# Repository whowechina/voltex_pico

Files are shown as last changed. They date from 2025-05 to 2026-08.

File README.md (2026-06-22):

# Voltex Pico - Sound Voltex Style Mini Controller
[点这里可以切换到中文版](README_CN.md)

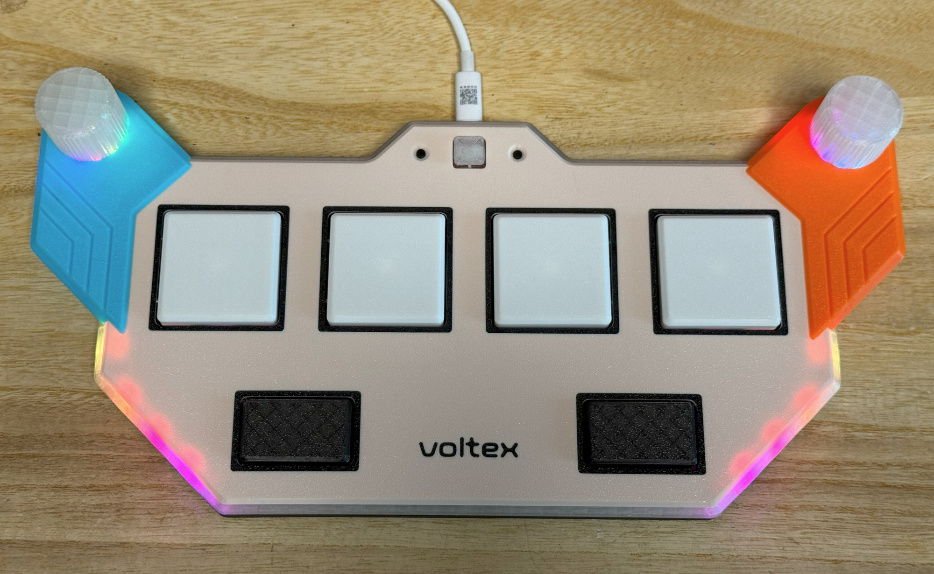
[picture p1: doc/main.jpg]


Features:
* It's ultra thin but closely replicates the feel of the arcade controller.
* Supports both Hall Effect (magnetic) switches and regular mechanical switches.
* Utilizing my new innovation: stabilizer mechanics for big and thin buttons.
* Hall Effect knobs.
* Full HID light support.
* Command line for configurations.
* All source files open.

Thanks to many respected guys/companies who made their tools or materials free or open source (KiCad, OnShape, InkScape, Raspberry things).

Special thanks to community projects and developers.
And also these projects:
* RP_Silicon_KiCad: https://github.com/HeadBoffin/RP_Silicon_KiCad
* Type-C: https://github.com/ai03-2725/Type-C.pretty
* USBemani: https://github.com/progmem/usbemani (for the Spoof mode USB descriptor)

## My Other Projects
You can check out my other cool projects.

               


* Popn Pico: https://github.com/whowechina/popn_pico
* IIDX Pico: https://github.com/whowechina/iidx_pico
* Chu Pico: https://github.com/whowechina/chu_pico
* Mai Pico: https://github.com/whowechina/mai_pico
* Diva Pico: https://github.com/whowechina/diva_pico
* AIC Pico: https://github.com/whowechina/aic_pico
* Groove Pico: https://github.com/whowechina/groove_pico
* Geki Pico: https://github.com/whowechina/geki_pico
* Musec Pico: https://github.com/whowechina/musec_pico
* Ju Pico: https://github.com/whowechina/ju_pico
* Bishi Pico: https://github.com/whowechina/bishi_pico
* Nos Pico: https://github.com/whowechina/nos_pico
* Voltex Pico: https://github.com/whowechina/voltex_pico
* Chord Pico: https://github.com/whowechina/chord_pico
* Dance Pico: https://github.com/whowechina/dance_pico
* Arcade Pico: https://github.com/whowechina/arcade_pico

## **Disclaimer** ##
I made this project in my personal time with no financial benefit or sponsorship. I will continue to improve the project. I have done my best to ensure that everything is accurate and functional, there's always a chance that mistakes may occur. I cannot be held responsible for any loss of your time or money that may result from using this open source project. Thank you for your understanding.

## About the License
It's CC-NC. So DIY for yourself and for your friend, don't make money from it. And plagiarism that doesn’t even dare to mention the original author is not acceptable. Please note that pooling orders and group buying for raw materials is acceptable. Selling off any leftover components without profit is also acceptable.

If you're interested in buying from me or some kind of commercial use, please contact me (Discord, QQ group, Wechat group or leave your contact in issue section).

## My Discord Invitation
https://discord.gg/M8f2PPQFEA

## HOW TO BUILD
### PCB and Components
* Go JLCPCB and make order with the gerber zip files (latest `Production\PCB\voltex_pico_xxx.zip`), regular FR-4 board, black or white color, **1.6mm** thickness.  
* 1x Rasberry Pico Pi Pico or pin-to-pin compatible clones (U1).  
  https://www.raspberrypi.com/products/raspberry-pi-pico
* 1x USB Type-C socket (918-418K2023S40001 or KH-TYPE-C-16P)
* 21x Reverse Mount WS2812B-3528 RGB LEDs (D1-D20).
* 18x WS2812B-4020 side emitting RGB LEDs (DL1-DL9, DR1-DR9).
* 2x TMAG-5273A1 or TMAG5273A2, in SOT23-6 (U3, U4).
* 50x 0603 0.1uF capacitors (all capacitors on the PCB, most of them are optional).
* 4x 0603 5.1kohm resistors (R1, R2, R3, R4).
* 12x U-shape 2U stabilizer steel wires, you can also harvest them from regular 2U MX stabilizers.
* 1x Kailh Choc switch for the START button (B7), and a matching blank translucent keycap.
* 2x ALPS SKHHBVA010 or compatible (6\*6\*7mm) tactile switches for the AUX buttons (B8, B9).
* 4x 1.0mm 6-pin FPC connectors, bottom contact, front flip.
* 2x 1.0mm 6-pin FPC cables, 25mm to 30mm long. Longer ones are also fine if bent properly.

* The following is for regular switch build.
  * 6x Kailh Choc low-profile switches. Choose heavy ones (70gf) for 4 BT buttons, and regular ones (50gf) for 2 FX buttons (B1-B6).

* The following is for Hall Effect switch build.
  * 1x ADG708BRUZ, 8 to 1 analog switch, in TSSOP-16 (U2).
  * 1x LM4040 Shunt Voltage Reference, get one with 2.0, 2.1, or 2.5 reference voltage, in SOT23-3 (U6).
  * 1x LP5907MFX-4.5 or TPS7A2042PDBVR LDO, in SOT23-5 (U7).
  * 6x SS49E or compatible linear Hall Effect sensors, in SOT23-3 (H1-H6).
  * 1x 10ohm resistor, 0603 (R5).
  * 1x 3.3V Zener diode, in SOD-123 or SOD-123F, such as BZT52H-C3V3 (Z1).
  * 6x low profile magnetic switches, Gateron/NuPhy Jade Mini or Jade Pro Mini, or Kailh Star Magnetic Mini. (B1-B6).
  * 4x heavy springs (60gF+) for low-profile switches, to replace the original ones in 4 BT switches. You may buy or harvest them from Kailh Choc heavy switches.

* This picture shows a soldered PCB (there might be changes in newer versions of PCB). It's a Hall Effect switch build.  
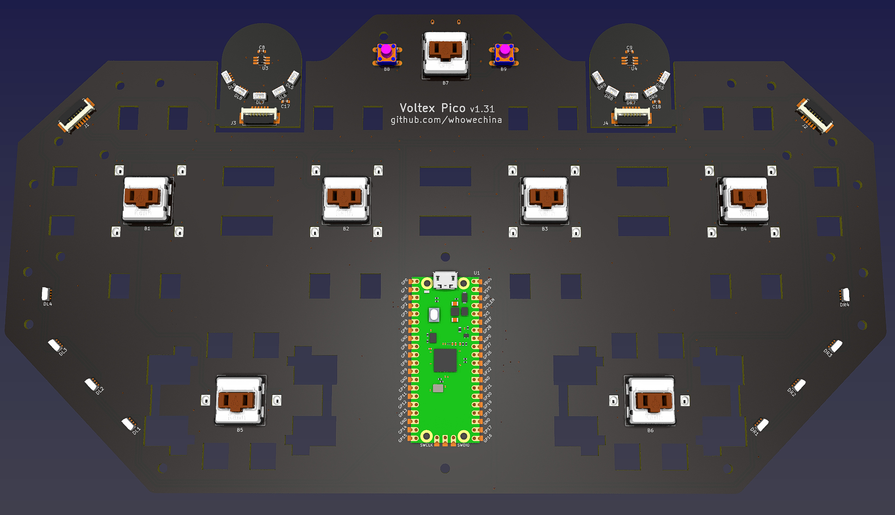
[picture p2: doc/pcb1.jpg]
    
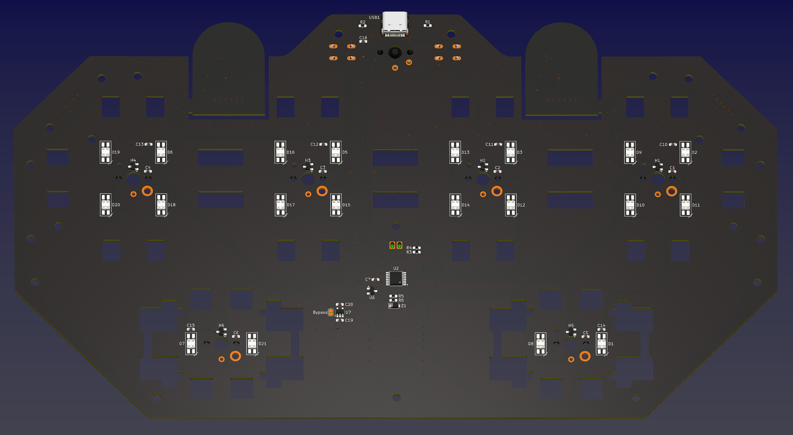
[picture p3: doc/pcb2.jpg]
  

### Important Tips for Soldering
* Be careful of 2 pin holes. It's a common oversight to either forget to solder them or to leave air bubbles during the process. To avoid this, solder slowly from one side of the hole, using minimal solder wire and a generous amount of flux.
* Reverse mount LEDs are soldered at the bottom side of the PCB.
* D4 actually requires a regular WS2812B-3528 RGB LED, not a reverse mount one. We can make one from a reverse mount one. Just bend the 4 feet to the bottom and it becomes a regular WS2812B-3528.  
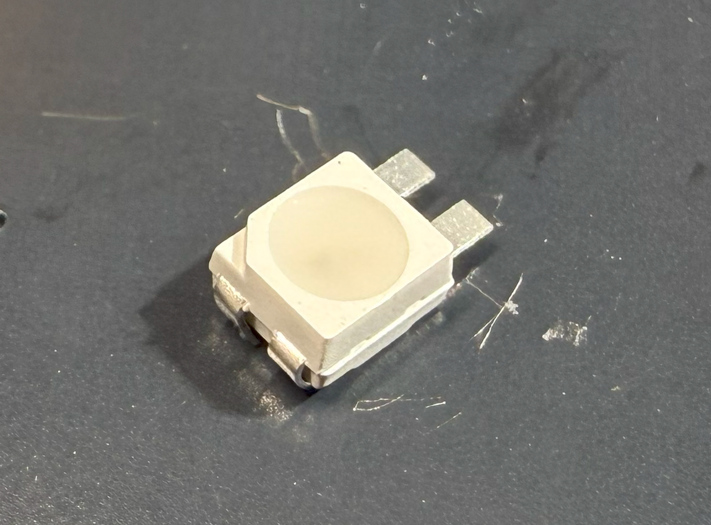
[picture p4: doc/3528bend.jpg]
  
* Be careful with WS2812B-4020 orientation. DL1 to DL4, and DR1 to DR4 are side facing, while the DL5 to DL9 and DR5 to DR9 are top facing. 
* Leave the DCDC (U5) empty and short the corresponding BYPASS jumper.
* You don't need to solder all the capacitors, it's fine to just solder the ones right beside ICs.
* Z1 is to protect the Pico from excessive voltage, don't ignore it.
* There are many LDOs and shunt voltage reference models, as long as they have the same form factor, pinout and voltage, you can use them. Best LDO voltages are 4.0 to 4.5V, they should not go higher than 4.5V, as the USB voltage under load could be lower than it. The shunt voltage reference should be 2.0 to 2.5V, roughly half of the LDO voltage.
* For regular switch build, you need to solder the switches onto the PCB. For Hall Effect switch build, you don't need to solder the switches, just make sure the magnets are aligned with the small white circles on the PCB.

### Test the PCB
* You can test the PCB now, put the firmware in.
* Side LEDs and Knob LEDs should light up in a rainbow pattern.
* Button LEDs respond to the button presses (magnetic switches need to be temporarily put on and calibrated).
* Voltex Pico should be recognized as a USB HID device, here's the test page.  
  https://whowechina.github.io/iidx_pico/Tools/gamepad_test.html
* Move a magnetic screwdriver tip close to the TMAG5273 sensor, you'll notice the corresponding axis move in the test page. Please check both sensors.

### Sensor PCB Separation and Soldering
* If everything works fine, you can cut off (or even bend and snap) 2 small sensor boards from the main board.
* Connect the sensor PCBs to the main PCB using FPC cables. Older PCB revisions do not have FPC connectors, so solder short flexible wires instead.  
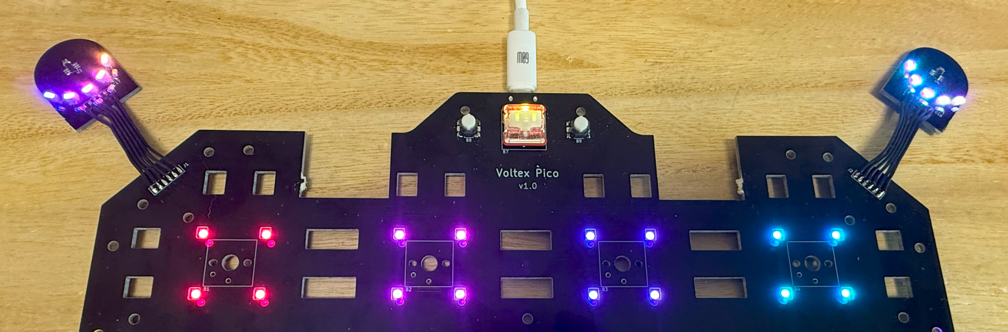
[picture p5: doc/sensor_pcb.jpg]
  

### 3D Printing
#### Printing parameters  
* PLA or PETG.
* Layer height: 0.2mm
* Support: No, unless mentioned.
* Files are always in millimeter unit, not inch.
* Files with `_Insert` in their names means it's for heatset inserts. M2 inserts are M2\*3mm\*3mm, M3 inserts are M3\*4mm\*4mm.

#### 2x Knob Parts
* Knob: `Production\3DPrint\* - Knob.stl`, clear, semi-transparent. Print it upside down. 
* Bearing Fixer: `Production\3DPrint\* - Bearing Fixer.stl`.
* Magnet Seat: `Production\3DPrint\* - Magnet Seat.stl`.

#### Button Parts
For regular switch build, choose Choc V1 or Choc v2 keycaps according to your switch type. For Hall Effect switch build, always choose Choc V2 ones.
**For all button keycaps, print them upside down.**
Note that if your switches are a little taller than usual, you need to use the `*_TallFix.stl` files for Main and FX buttons.

* Main BT: `Production\3DPrint\* - BT Choc V?.stl`, white.
* FX BT: `Production\3DPrint\* - FX-? Choc V?.stl`, smokey transparent. Support required.

#### Wing Parts
* Wing Base: `Production\3DPrint\* - * Wing Base.stl`, black.
* Wing Cover: `Production\3DPrint\* - * Wing Cover.stl`, cyan for the left, orange for the right. Print it upside down.

### Housing Parts
* Base: `Production\3DPrint\* - Base.stl`, black.
* Support: `Production\3DPrint\* - Support.stl`, clear, semi-transparent.
* Panel: `Production\3DPrint\* - Panel Combo.3mf`, white or close-to-white, with logo and patterns in black if you have multi-color system. Print it upside down.  

### Thin Stabilizing Mechanism for Big Button 
Before assembly, I'm going to introduce a new thin stabilizing mechanism for big buttons. I designed it so a slim Voltex Pico is possible.

Stabilizing a button means to make the button not wobble when pressed. A wobbling button is like a seesaw, corners for the button don't go up and down in sync, which makes the button feel bad and not reliable.

Stabilizing a big button is never a problem for arcade, simply because arcade cabs have enough vertical space. They can use so called "tube guide" stabilizing. As long as the tube is long enough (versus the gap between the tube and the shaft), buttons can only move or twist horizontally a little bit, but never wobble like a seesaw. 

Technically, for a slim controller which only has millimeters of vertical space, we can still use tube guide, but such a small tube and shaft will be very difficult to make or harvest, not to mention the sliding surface material. In short words, it's not feasible for DIYers. So we have to use a lever based stabilizing mechanism, like we do in the modern keyboards.

Long keyboard keycaps are "1-dimensional", you only need one stabilizer on their X-axis. But for big arcade buttons - big cicle or square - they need "2-dimensions" of stabilizing. So people just drop in 2 stabilizers, placed perpendicular to each other. Technically this will work. But there come new problems.
  * Vertical space for the stem and the stabilizer is not ideal for a slim controller.
  * Requires accurate keycap stem holes (connecting both the keyswitch and the stabilizer), tiny misalignment can cause stress and bring excessive friction.
  * Both FDM and SLA 3D printing have their own tolerances, which can cause misalignment easily.

So here I'm introducing my way.
First of all, I'm still using a lever-based stabilizing, just like the one in keyboards. A keyboard stabilizer has a U-shape steel lever which stays in two housing units (we call them "stabilizer base"). It rotates around its shaft side and drives two connectors (stems) to move up and down simultaneously.

My change is, remove the housing units and the stems, let the U-shape steel lever drive the keycap directly. With the stems removed, coupling of the keycap and the lever is much more lenient to misalignment; with the housing units removed, the vertical space is much smaller, which is ideal for a slim controller.

The "bearing" for the lever is printed along with the the bottom housing. The keycaps have small holes for the lever arms to go through. A FDM 3D printer can print them easily.

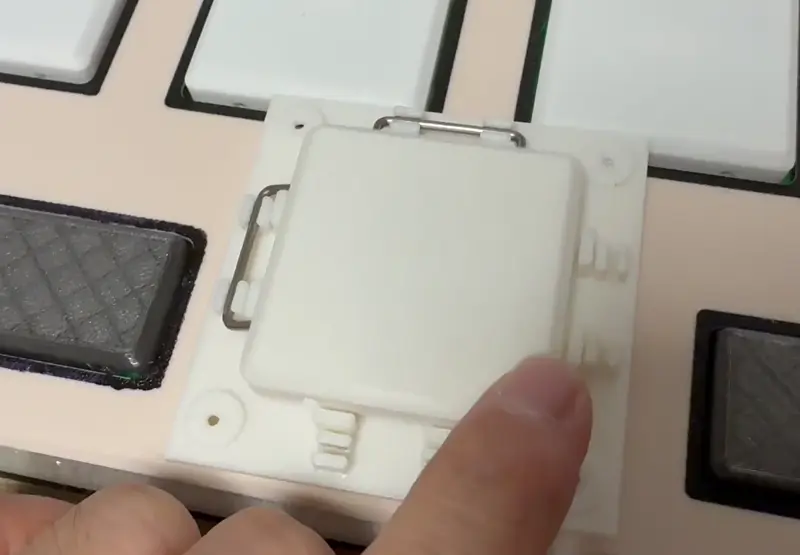
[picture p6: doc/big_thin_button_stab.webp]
  

The Voltex Pico uses this new stabilizing mechanism for the big BT buttons as well as the FX buttons.

### Assembly
#### Other components needed
* 6x **M2.5\*(14mm-16mm) screws** for fixing the magnet seat to the knob.
* 8x **M2\*6mm screws** for fixing the bearing (bearing fixer to the wing cover).
* 6x **M2\*8mm screws** for fixing wing bases to the wing cover, **M2\*6mm** if using heatset inserts.
* 12x **M3\*(4mm-5mm) screws** for fixing the PCB to the base parts.
* 10x **M3\*8mm screws** for fixing the base, wing base, support and the panel. **M3\*6mm** if using heatset inserts.
* 2x 6702zz (15x21x4mm) bearings for the knobs.
* 2x round magnets, 5mm diameter, 1.5mm or 2mm tall, MUST be radially/diametrically magnetized (N-S poles on the curved side).
* Some thin tape (such as acetate tape or high-temp teflon tape) to fix the magnets in place.
* Some 10mm diameter silicone anti-slip pads for the bottom.  
* Some 1mm thick soft felt sheet for damping the knobs.

#### Steps
1. We'll start with the bearings. They should be inserted into wing parts. Fix them using bearing fixers and M2\*6mm screws.  
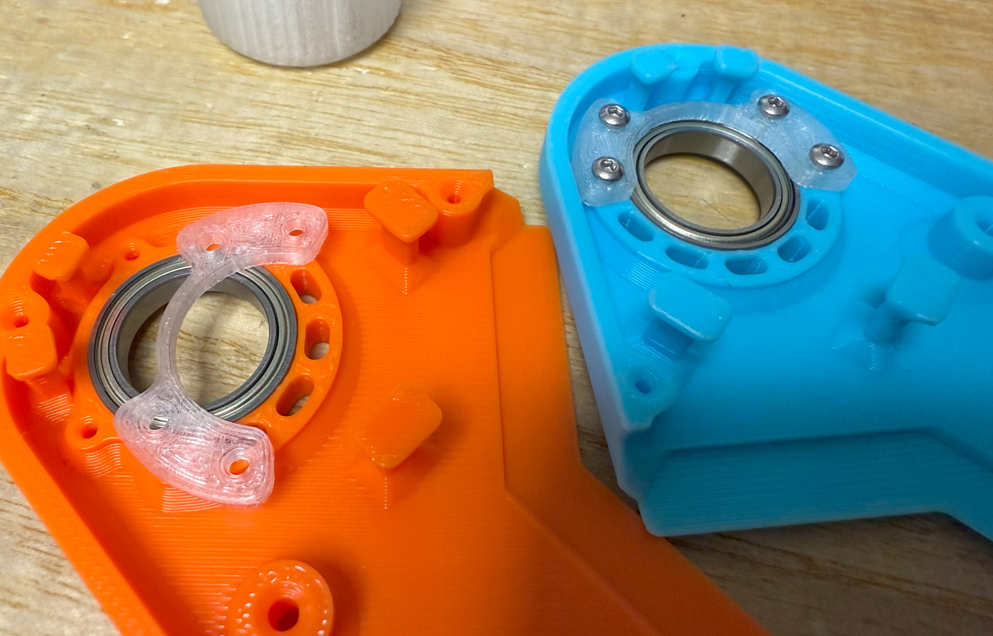
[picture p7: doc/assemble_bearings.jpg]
   

2. Cut a ring from the soft felt sheet to dampen the knob. If you feel this is too difficult, you can apply some layers of felt between the knob and the sensor PCB, it works too.   
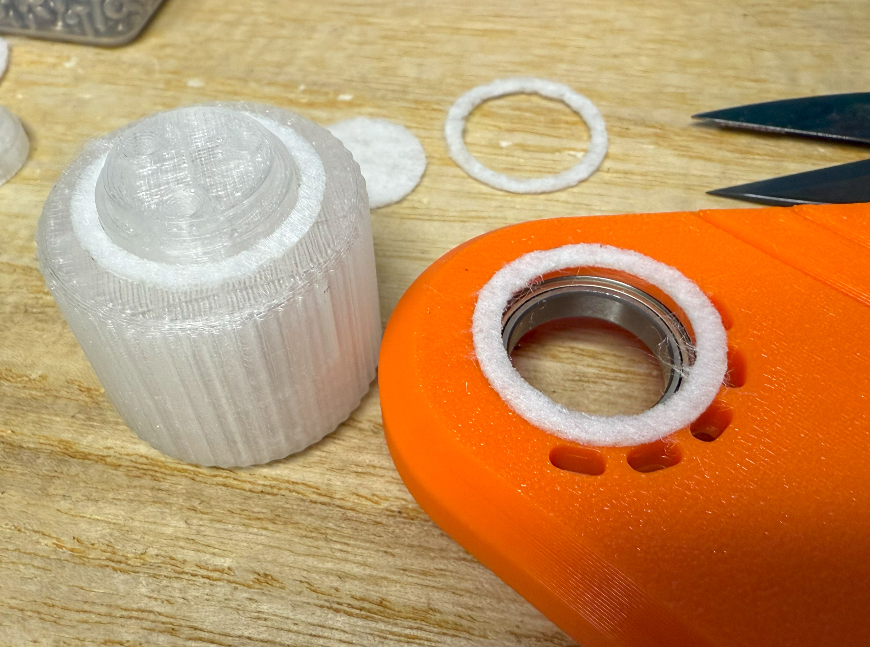
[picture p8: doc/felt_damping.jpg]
   

3. Fix the knob to the bearing with the magnet set and the M2.5 screws (long screws help reinforce the knob shaft). Then put the magnet into the center seat. If you have some thin tape, apply it as a seal so magnet won't fall out.  
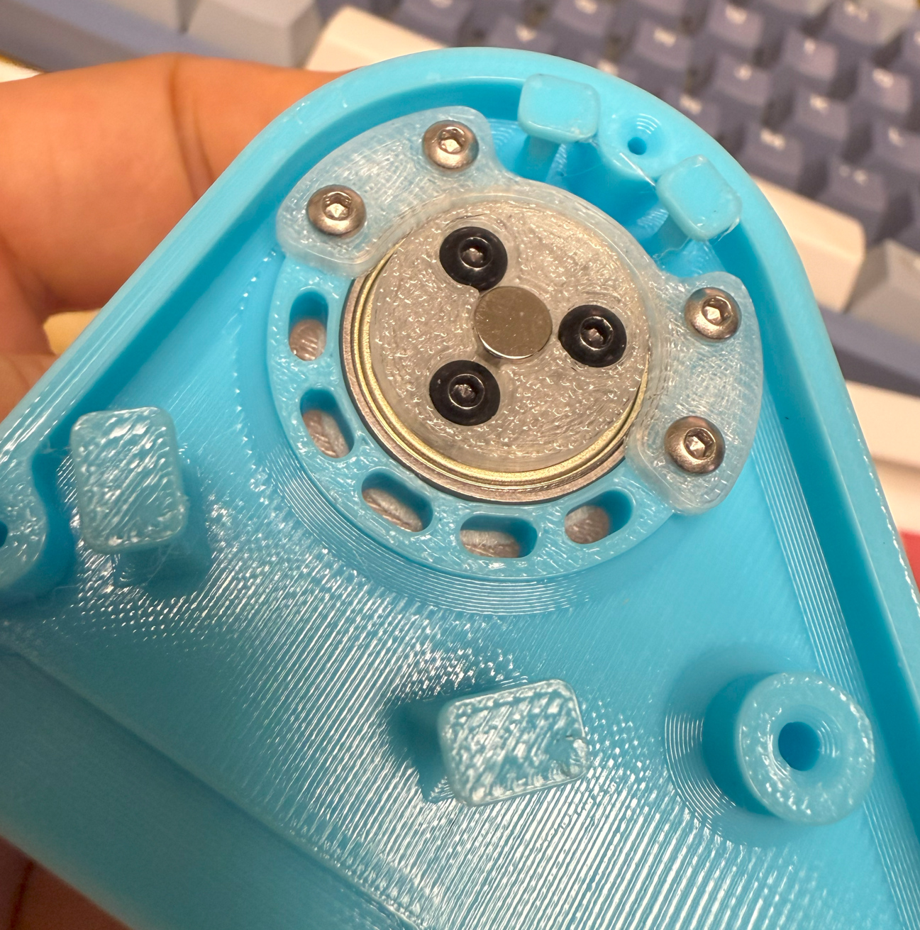
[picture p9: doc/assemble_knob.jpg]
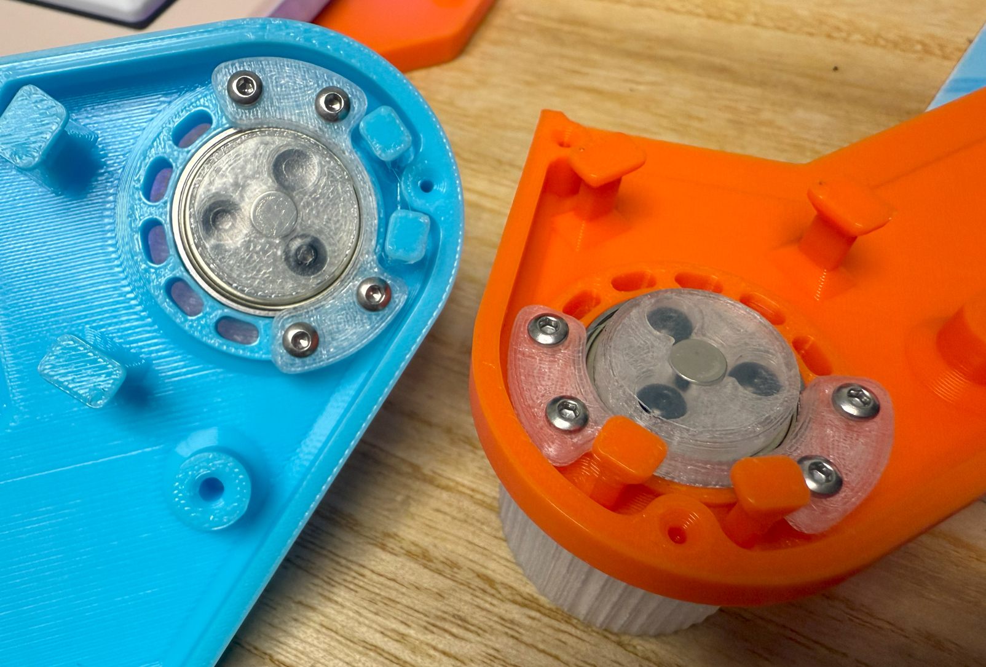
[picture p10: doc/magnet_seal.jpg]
    

4. Put the main PCB into the base part, and sensor PCBs into the wing base parts. Use M3\*(4mm-5mm) screws to fix the PCB to the base parts.  
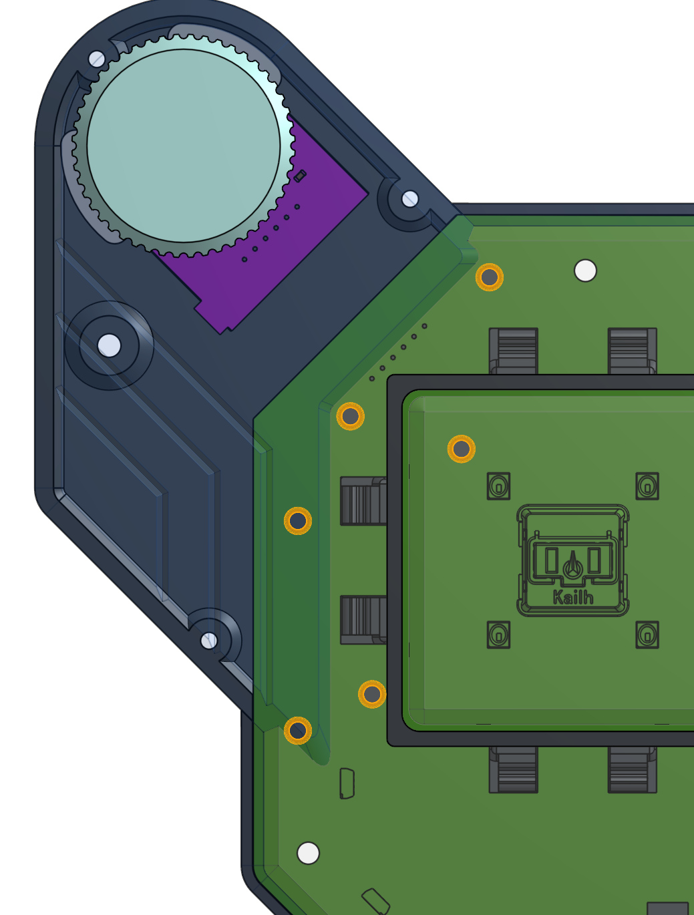
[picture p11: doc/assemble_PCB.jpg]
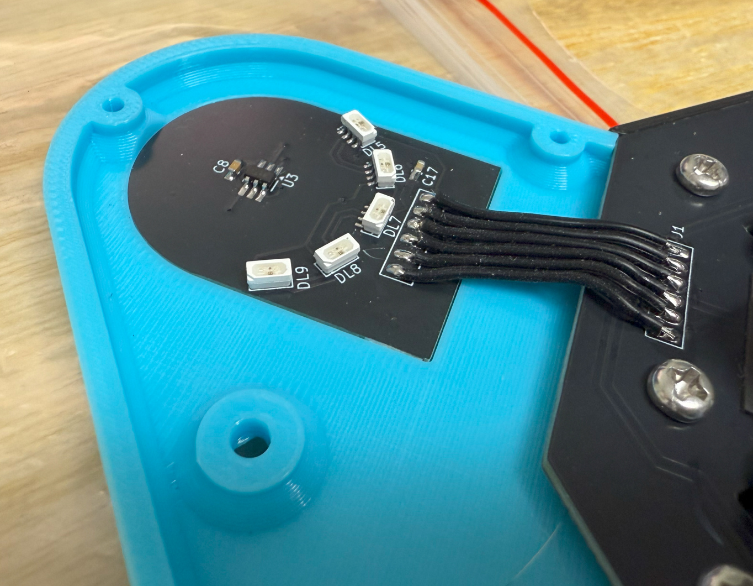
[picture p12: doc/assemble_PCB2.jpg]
    

5. Time to install keycaps to the stabilizer. It's simple, just look at the pictures. You can apply some thin poron pads to dampen the keycap noise, but it's not necessary. Some lubricant can be applied to the lever shaft, this makes the movement smoother. For Hall Effect version, you can use 704 RTV silicone to stick the switches to the PCB, or not - it's totally fine.  
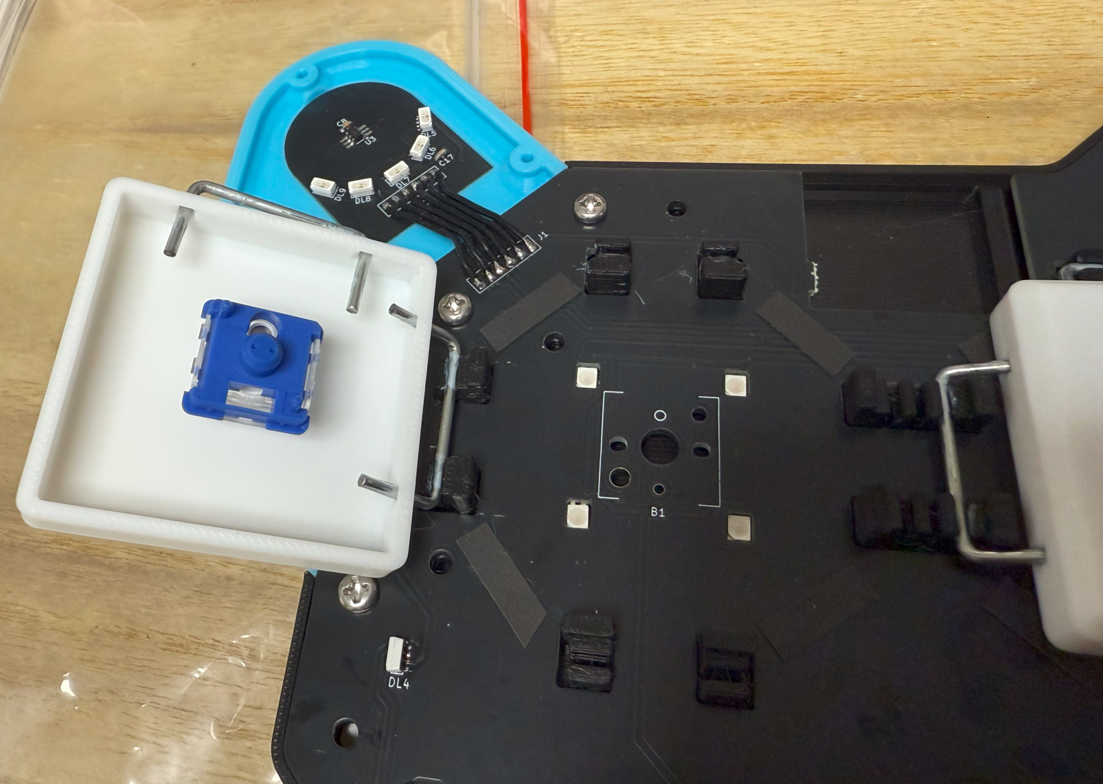
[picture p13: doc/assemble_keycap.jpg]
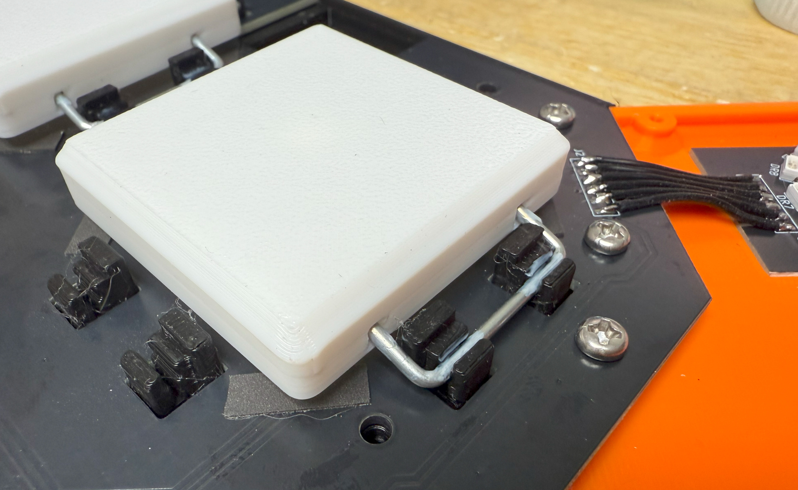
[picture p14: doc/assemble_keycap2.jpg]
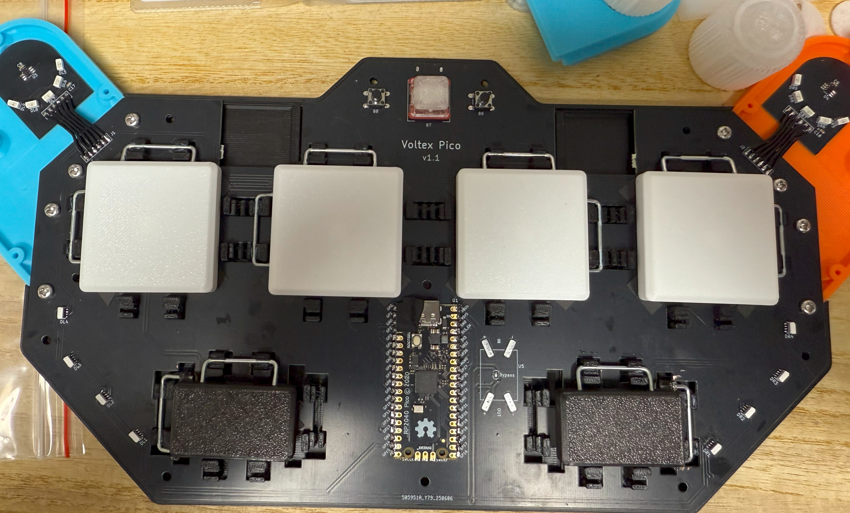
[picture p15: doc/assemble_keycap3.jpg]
     

6. Put on the support and the panel. Use M3\*(8mm-10mm) screws to fix the base. Leave the two screws on the wing base empty for now.

7. Put on the wing covers (which already have knobs on them), use M2\*(8mm-10mm) screws to fix them to the wing cover (see the picture for M2 screws). And use M3\*(8mm-10mm) screws on the remaining screw holes (one at each side). Apply silicone pads, they don't look nice but they prevent the controller from sliding on the table.   
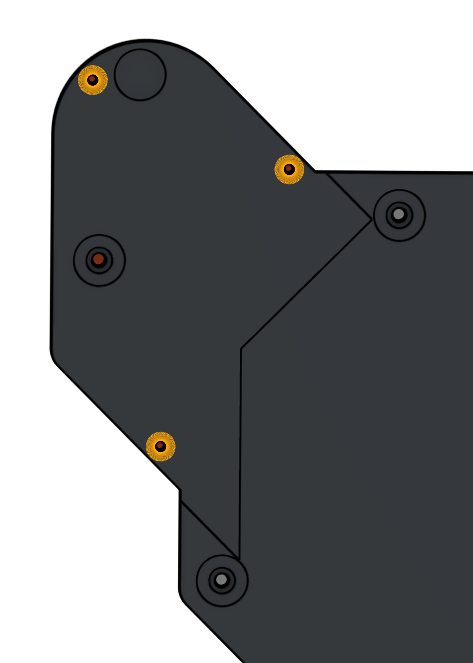
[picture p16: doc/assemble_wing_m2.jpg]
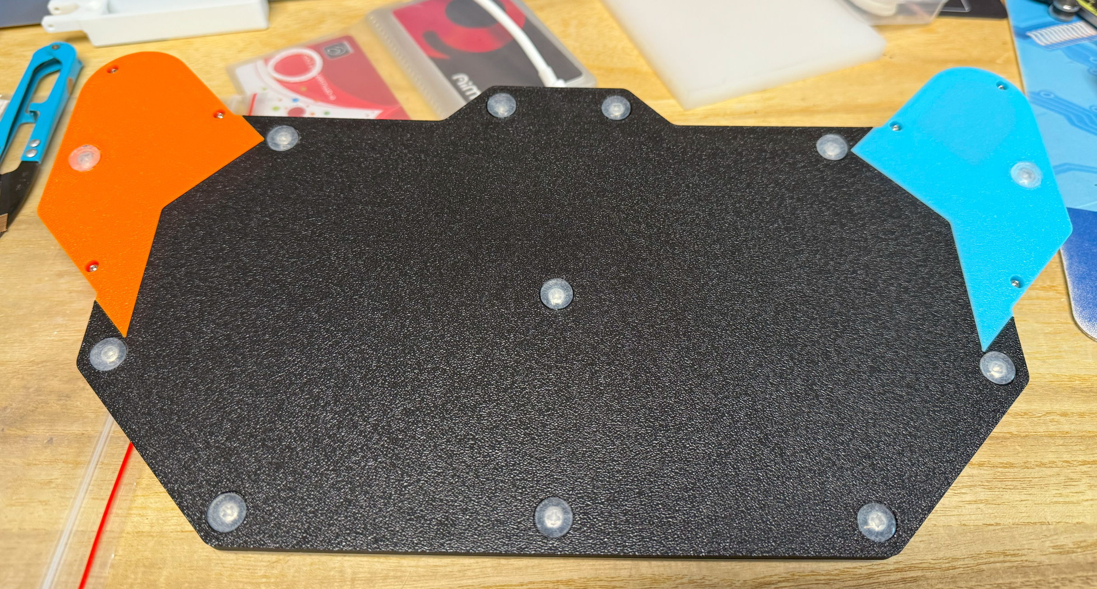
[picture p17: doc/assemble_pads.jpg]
    
   
8. Congratulations! You have finished the assembly.  
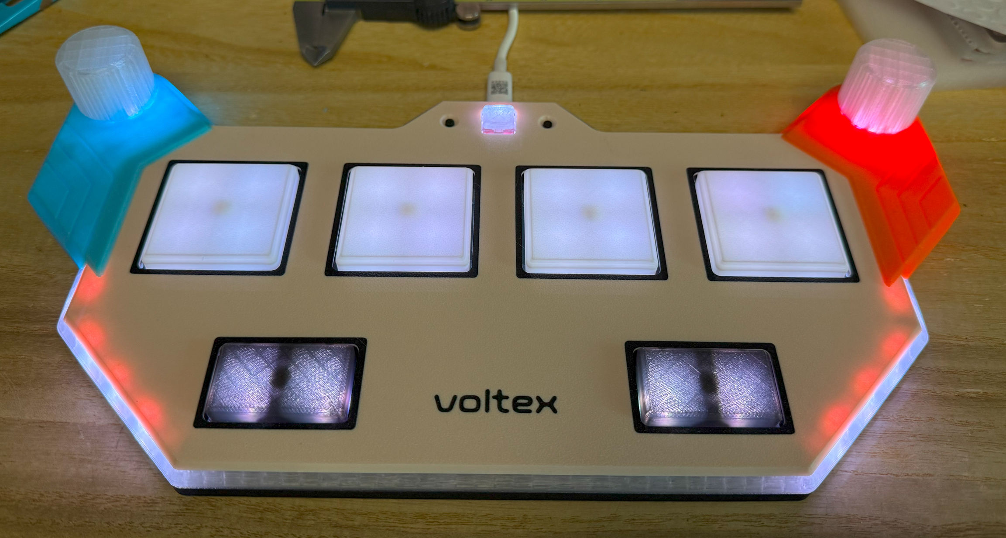
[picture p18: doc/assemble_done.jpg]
   

#### Caution
* Each 3D printer and filament has its own tolerance. If you find the holes on the keycap are too tight, use a needle or knife to enlarge them a little bit.
* Screws are easy to break the 3D printed parts. So don't screw them too tight. When you notice the resistance suddenly increases, stop screwing.

### Firmware
* UF2 file is in `Production\Firmware` folder.
* For the new build, hold the BOOTSEL button while connect the USB to a PC, there will be a disk named "RPI-RP2" show up. Drag the UF2 firmware binary file into it. That's it. There's a small hole at the bottom side, it is facing right to the BOOTSEL button.
* If it's already running Voltex Pico firmware, you can either use "update" in command line or hold down at least 4 buttons while connecting to USB to enter update mode.
* To access the command line, you can use this Web Serial Terminal to connect to the USB serial port of the controller. (Note: "?" is for help)  
  https://whowechina.github.io/iidx_pico/Tools/cli_tool.html

### Usage
* If you built a Hall Effect switch version, you need to calibrate first (`calibrate` command). You can set trigger and reset point in command line.
* Just plug it in and play.
* You can set knob resolution by `knob rate` command.
* You can set trigger and reset point by `trigger` command (only for Hall Effect switch version).
* Hold the left auxiliary button while plugging in to enter Konami spoof mode; the right for regular mode.

## CAD Source File
I'm using OnShape free subscription. It's powerful but it can't archive original designs to local, so I can only share the link here. All model files are exported from this online document.  
  https://cad.onshape.com/documents/757c9485a30088ef0335481e/w/af98e079c47cba7d81086e65/e/9703cb81cc6ed9c6ec563897

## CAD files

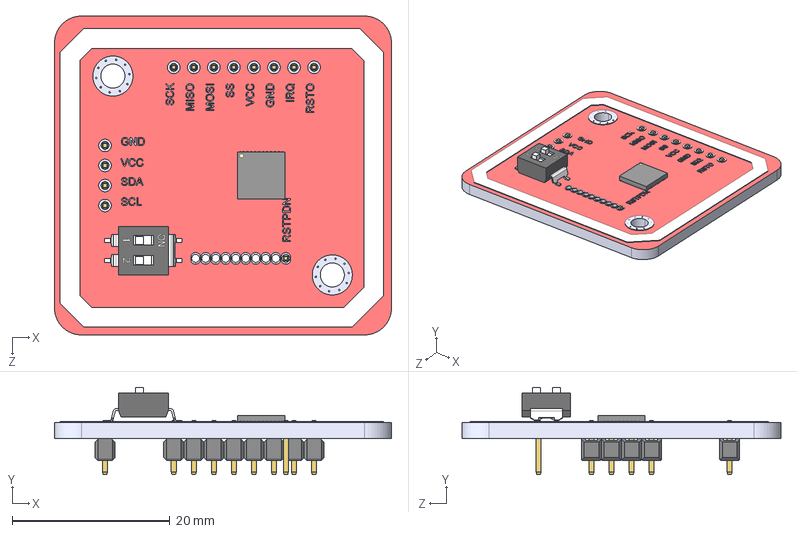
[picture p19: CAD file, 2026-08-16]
PCB/jumbo/3dmodels/PN532_NFC_Assembly.STEP
42.7 x 11.0 x 40.4 mm
NFC_MODULE_1
Pin Stand 2.54mm_1 x 12
QFN40 (6x6)_1
Switch_2_1
pin_my_1 x 13

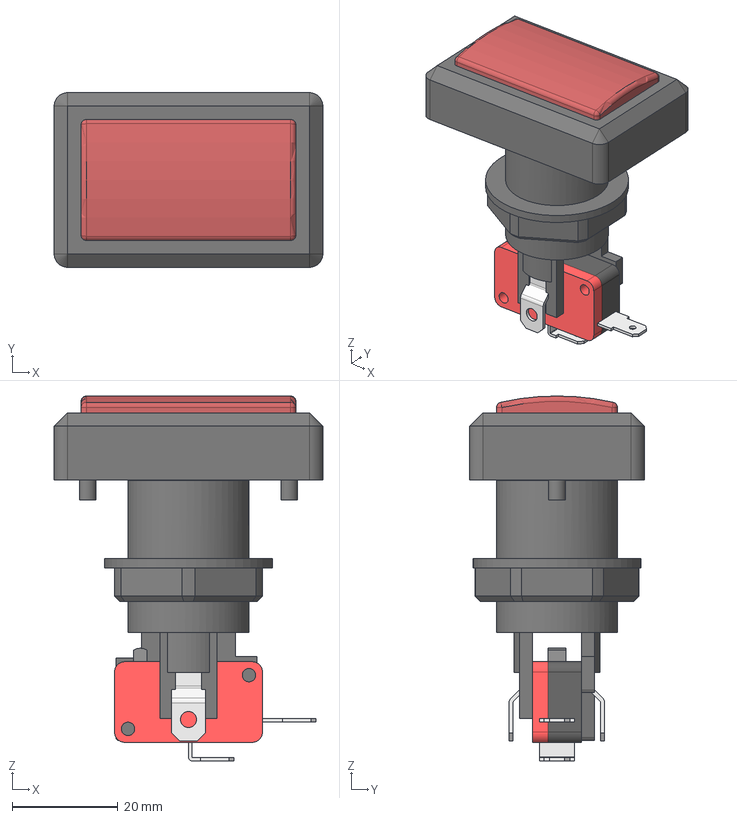
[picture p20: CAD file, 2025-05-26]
PCB/jumbo/3dmodels/Credit Button Assy (Groovy).step
50.8 x 33.0 x 69.0 mm
Button
Nut
Switch

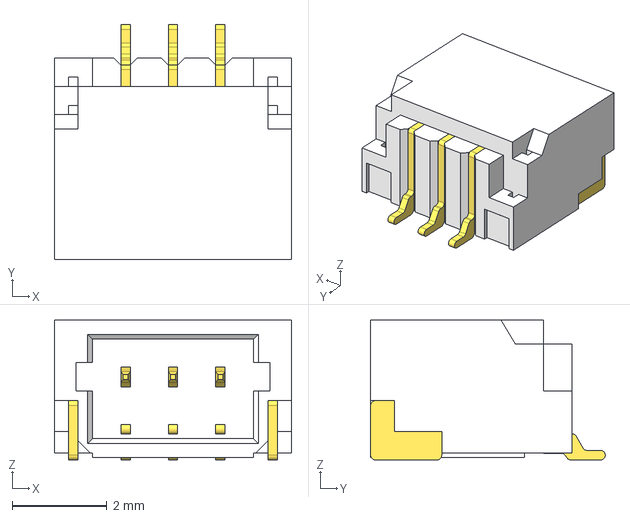
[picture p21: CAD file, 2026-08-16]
PCB/jumbo/3dmodels/SM3B-SRSS-TB.step
5.00 x 4.95 x 2.95 mm

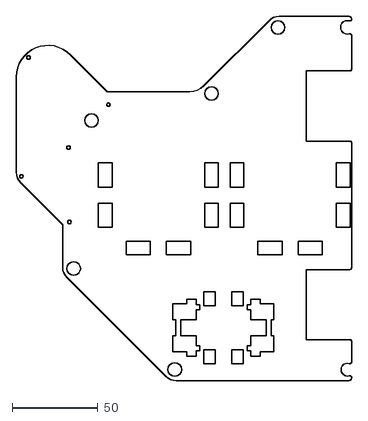
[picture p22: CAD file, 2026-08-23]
PCB/jumbo/Voltex Jumbo - PCB EdgeCut.dxf
195.9 x 212.8

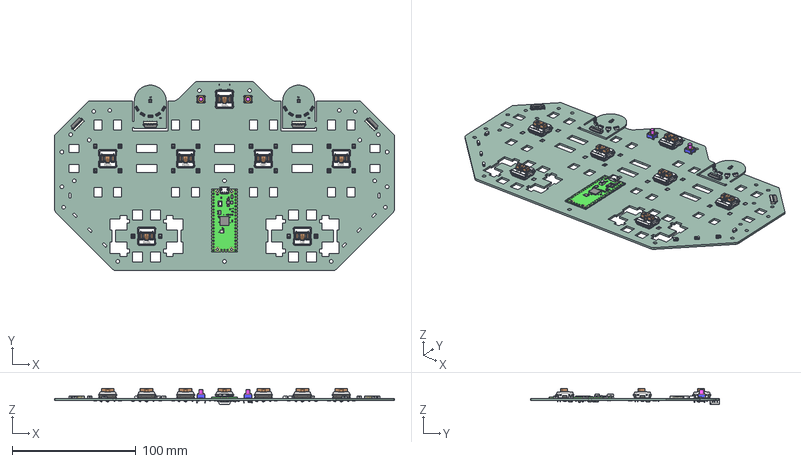
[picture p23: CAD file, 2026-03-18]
PCB/pico/voltex_pico_3d.step
275.0 x 153.0 x 13.1 mm
User Library-WS2812-4020 x 18
SMD WS2812B-3535 x 21
skhhbva010 x 2
FPC6P_1.0mm_Bottom_Contact_Flip x 4
PCB, Raspberry Pi Pico-R3
MicroUSB Port, Raspberry Pi Pico-R3
RP2040 Microcontroller, Raspberry Pi Pico-R3
SW1, Tact Switch, Raspberry Pi Pico-R3
D1, Diode, Schottky, Raspberry Pi Pico-R3
D2, QSME-C194, LED, Raspberry Pi Pico-R3
L1, Inductor, Raspberry Pi Pico-R3
U2, RT6150B-33GQW, Buck Boost Converter, Raspberry Pi Pico-R3
U3, W25Q16JVUXIQ, Serial NOR Flash 16 Mbit, Raspberry Pi Pico-R3
Q1, MOSFET, DMG1012T, Raspberry Pi Pico-R3
X1, X12M000000S096, 12 Mhz Crystal Resonator, Raspberry Pi Pico-R3
SMD Resistor, Configurable, Raspberry Pi Pico-R3_R1
SMD Resistor, Configurable, Raspberry Pi Pico-R3_R2
SMD Resistor, Configurable, Raspberry Pi Pico-R3_R3
SMD Resistor, Configurable, Raspberry Pi Pico-R3_R4
SMD Resistor, Configurable, Raspberry Pi Pico-R3_R5
SMD Resistor, Configurable, Raspberry Pi Pico-R3_R6
SMD Resistor, Configurable, Raspberry Pi Pico-R3_R7
SMD Resistor, Configurable, Raspberry Pi Pico-R3_R8
SMD Resistor, Configurable, Raspberry Pi Pico-R3_R9
SMD Resistor, Configurable, Raspberry Pi Pico-R3_R10
SMD Resistor, Configurable, Raspberry Pi Pico-R3_R11
SMD Resistor, Configurable, Raspberry Pi Pico-R3_R12
SMD Resistor, Configurable, Raspberry Pi Pico-R3_R13
SMD Resistor, Configurable, Raspberry Pi Pico-R3_R14
SMD Resistor, Configurable, Raspberry Pi Pico-R3_R15
SMD Capacitor, Configurable, Raspberry Pi Pico-R3_C1
SMD Capacitor, Configurable, Raspberry Pi Pico-R3_C2
SMD Capacitor, Configurable, Raspberry Pi Pico-R3_C3
SMD Capacitor, Configurable, Raspberry Pi Pico-R3_C4
SMD Capacitor, Configurable, Raspberry Pi Pico-R3_C5
SMD Capacitor, Configurable, Raspberry Pi Pico-R3_C6
SMD Capacitor, Configurable, Raspberry Pi Pico-R3_C7
SMD Capacitor, Configurable, Raspberry Pi Pico-R3_C8
SMD Capacitor, Configurable, Raspberry Pi Pico-R3_C9
SMD Capacitor, Configurable, Raspberry Pi Pico-R3_C10
SMD Capacitor, Configurable, Raspberry Pi Pico-R3_C11
SMD Capacitor, Configurable, Raspberry Pi Pico-R3_C12
SMD Capacitor, Configurable, Raspberry Pi Pico-R3_C13
SMD Capacitor, Configurable, Raspberry Pi Pico-R3_C14
SMD Capacitor, Configurable, Raspberry Pi Pico-R3_C15
SMD Capacitor, Configurable, Raspberry Pi Pico-R3_C16
SMD Capacitor, Configurable, Raspberry Pi Pico-R3_C17
SMD Capacitor, Configurable, Raspberry Pi Pico-R3_C18
C_0603_1608Metric x 20
SW_Kailh_Choc_V1 x 7
TSOT-23-6 x 2
D_SOD-123F
Insulator 698B116-X64-211
Contacts 698B116-X64-211
Shell 698B116-X64-211
R_0603_1608Metric x 6
SOT-23-3 x 7
TSSOP-16_4.4x5mm_P0.65mm
SOT-23-5
voltex_pico_PCB

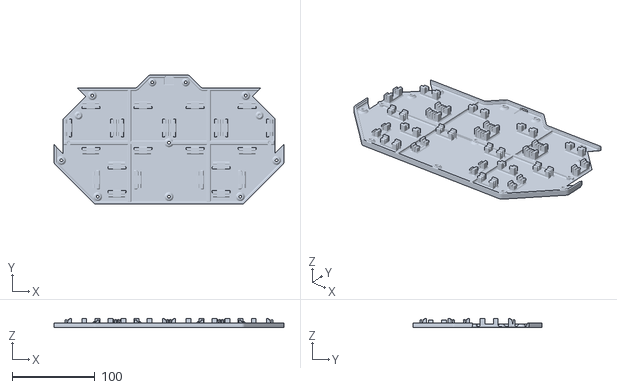
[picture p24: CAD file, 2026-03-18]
Production/3DPrint/Voltex Pico - Base.stl
278.2 x 156.2 x 11.4

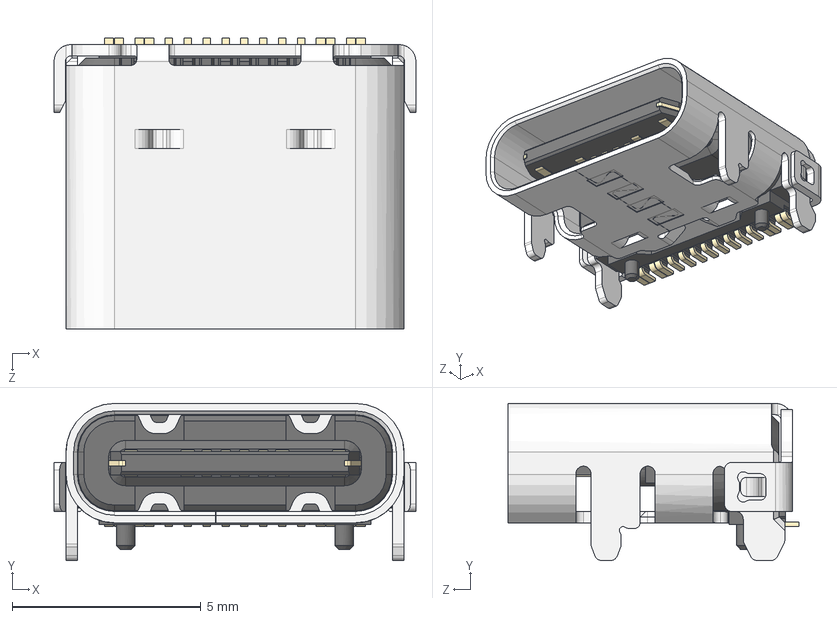
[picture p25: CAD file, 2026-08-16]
PCB/jumbo/3dmodels/698b116-264-211.STEP
9.58 x 4.16 x 7.71 mm
Insulator 698B116-X64-211
Contacts 698B116-X64-211
Shell 698B116-X64-211

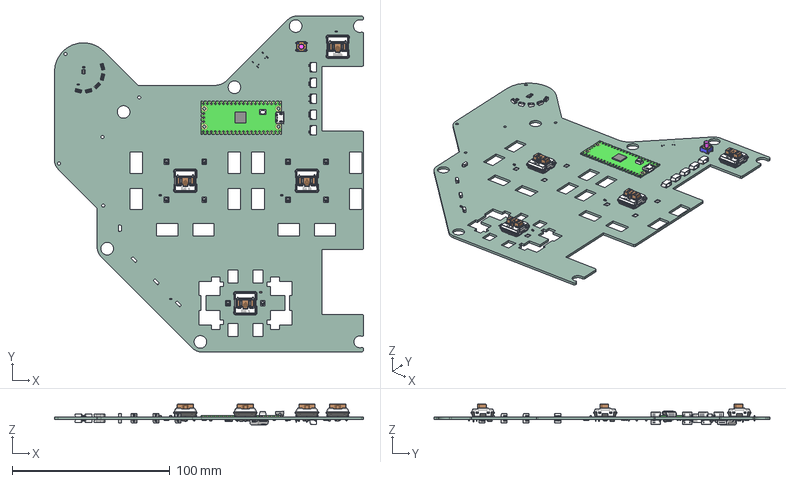
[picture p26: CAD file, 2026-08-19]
PCB/jumbo/voltex_jumbo_3d.step
195.9 x 212.8 x 13.1 mm
4778F300-7501-4A7A-8274-3BA11C4BFE81 x 18
skhhbva010
SMxB-SRSS-TB x 9
PCB, Raspberry Pi Pico-R3
MicroUSB Port, Raspberry Pi Pico-R3
MicroUSB Port, Raspberry Pi Pico-R004
RP2040 Microcontroller, Raspberry Pi Pico-R3
SW1, Tact Switch, Raspberry Pi Pico-R3
C_0603_1608Metric x 18
SOT-23-3 x 7
TSOT-23-6 x 2
SW_Kailh_Choc_V1_cp x 4
SMD WS2812B Mini v6 x 11
D_SOD_123F
Insulator 698B116-X64-211
Contacts 698B116-X64-211
Shell 698B116-X64-211
R_0603_1608Metric x 6
TSSOP-16_4.4x5mm_P0.65mm
SOT-23-5
voltex_jumbo_PCB

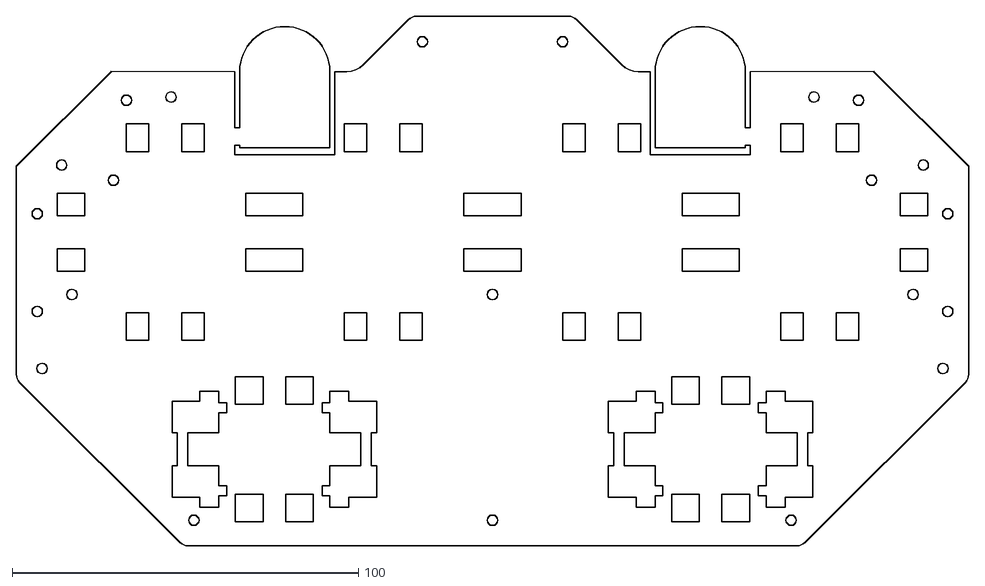
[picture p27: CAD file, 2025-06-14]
PCB/pico/Voltex Pico - PCB Profile.dxf
275.0 x 153.0

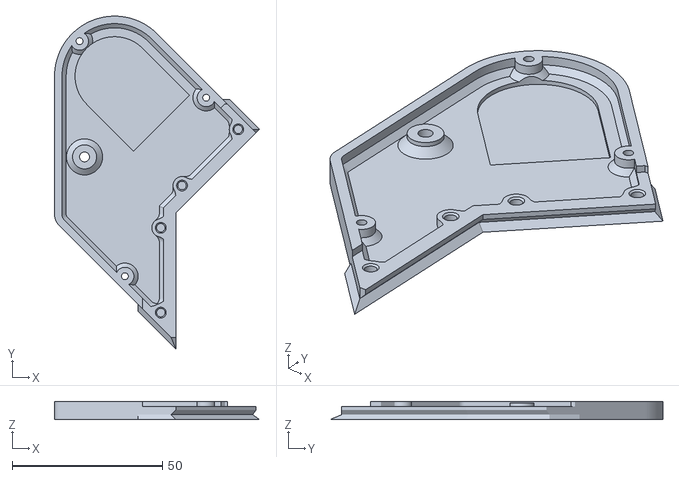
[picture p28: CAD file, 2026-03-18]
Production/3DPrint/Voltex Pico - Left Wing Base.stl
68.2 x 110.7 x 6.00

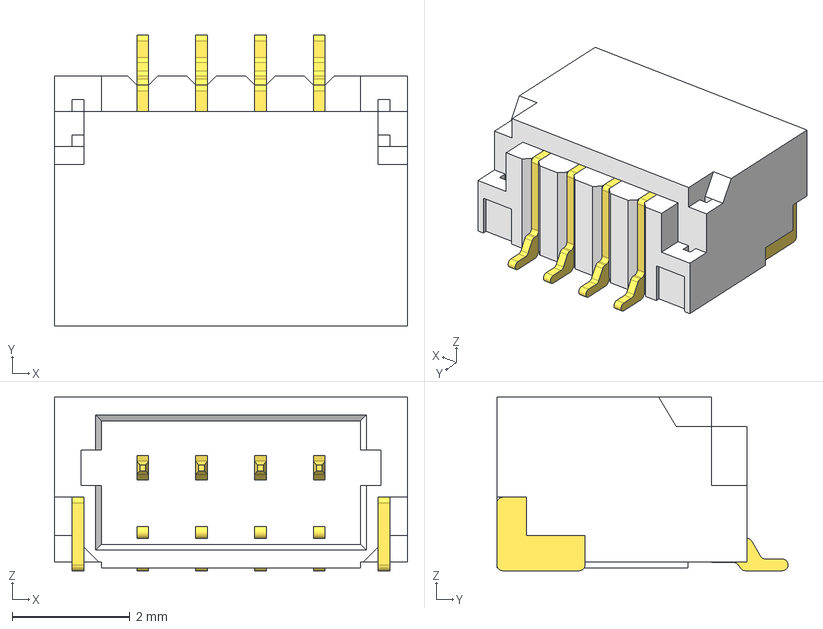
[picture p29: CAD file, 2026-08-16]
PCB/jumbo/3dmodels/SM4B-SRSS-TB.step
6.00 x 4.95 x 2.95 mm

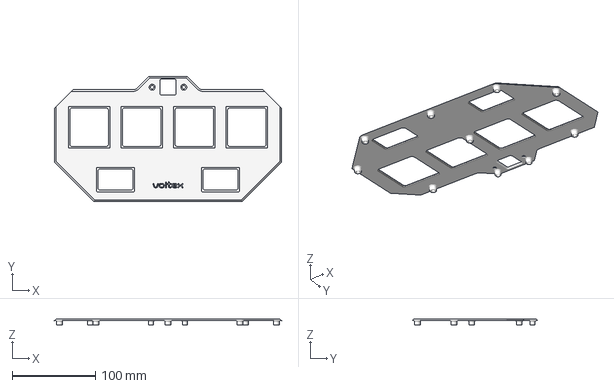
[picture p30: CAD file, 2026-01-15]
Production/3DPrint/Voltex Pico - Panel Combo.3mf
272.2 x 150.2 x 7.42 mm

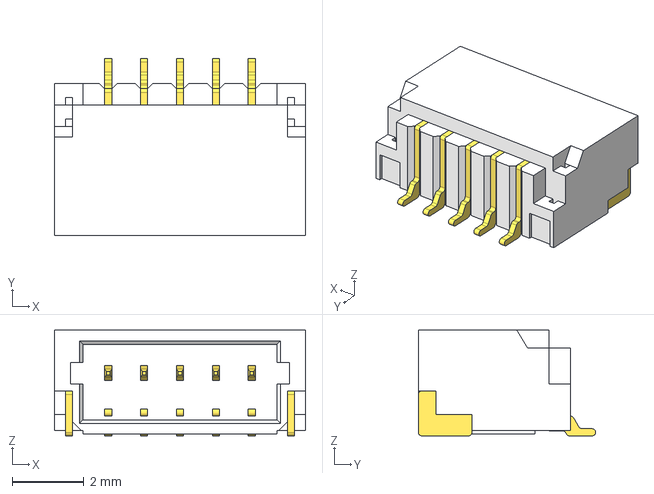
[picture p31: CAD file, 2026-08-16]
PCB/jumbo/3dmodels/SM5B-SRSS-TB.step
7.00 x 4.95 x 2.95 mm

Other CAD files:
PCB/jumbo/3dmodels/iidx_keycap_main_step.stp
res/voltex_jumbo_font_axion.dxf
res/Logo_font_axion.dxf
Production/3DPrint/Voltex Pico - Right Wing Base.stl
Production/3DPrint/Voltex Pico - Panel Combo_Insert.3mf
PCB/jumbo/3dmodels/gp2y0e03.scad
PCB/jumbo/3dmodels/keypad_lgp.scad
PCB/jumbo/3dmodels/530470310.stp
PCB/jumbo/3dmodels/8002A.step
PCB/jumbo/3dmodels/Button Cap.step
PCB/jumbo/3dmodels/EVQ-P1D05M.stp
PCB/jumbo/3dmodels/FPC0.5MM1.0H18P.step
PCB/jumbo/3dmodels/FPC6P_1.0mm_Bottom_Contact_Flip.stp
PCB/jumbo/3dmodels/Geki_Slider.step
PCB/jumbo/3dmodels/J 2835.step
PCB/jumbo/3dmodels/Kailh LP Choc PC Keycap.step
PCB/jumbo/3dmodels/Kailh_PG1353.STEP
PCB/jumbo/3dmodels/LED_WS2812_2020.step
PCB/jumbo/3dmodels/Raspberry Pi Pico-R3.step
PCB/jumbo/3dmodels/SKPMAM.STEP
PCB/jumbo/3dmodels/SKRRABE010.stp
PCB/jumbo/3dmodels/SKSTAAE010.stp
PCB/jumbo/3dmodels/SM04B-SRSS-TB.STEP
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

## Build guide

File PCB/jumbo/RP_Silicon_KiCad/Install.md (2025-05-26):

# Install KiCad libraries

## Manage Symbol Libraries

Accessed from the Preferences menu, add a new line with the +, give it a name and use the folder icon to point to the directory/folder where you have KiCadLibraries.

Manage Symbol Libraries screen shot


## Manage Footprint Libraries

Ditto! Accessed from the Preferences menu, add a new line with the +, give it a name and use the folder icon to point to the directory/folder where you have KiCadLibraries.

Manage Footprint Libraries screen shot


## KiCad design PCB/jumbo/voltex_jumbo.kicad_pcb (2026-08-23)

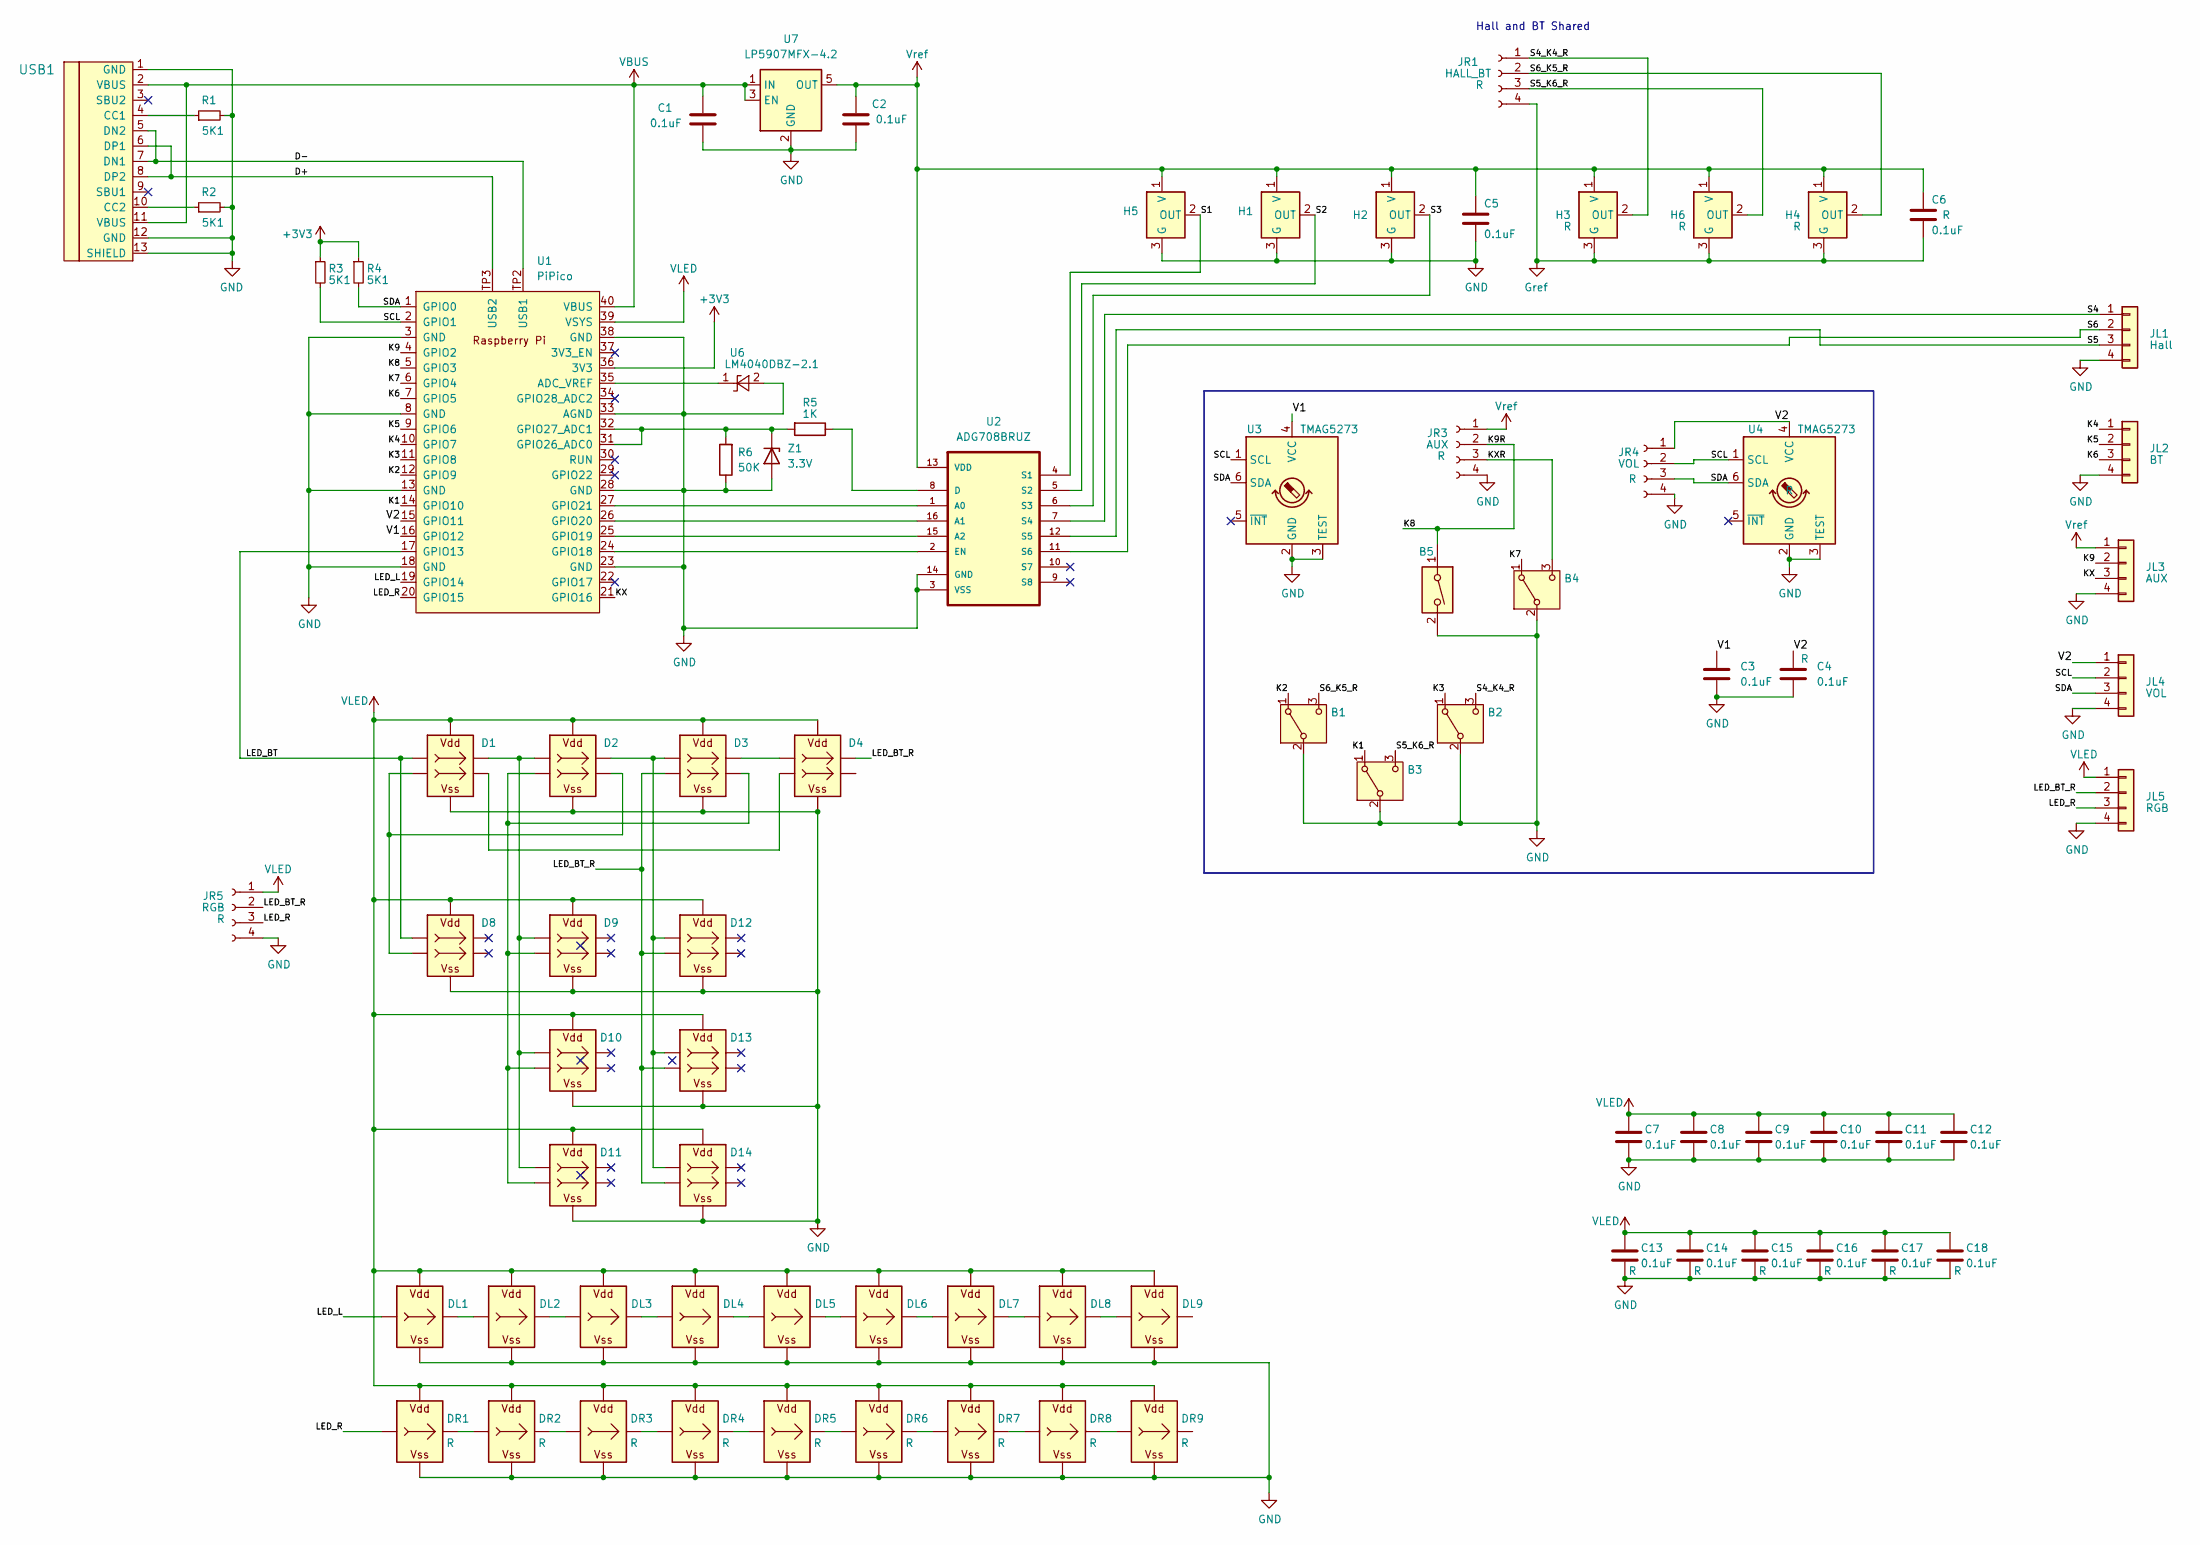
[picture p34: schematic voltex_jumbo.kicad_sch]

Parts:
B1, B2, B3: ChocHE; Choc_HE_DoubleSide
B4: ChocHE; Choc_DoubleSide
B5: SW_DIP_x01; SW_SKHHANA010
C1, C2, C3, C4, C5, C6, C7, C8, C9, C10, C11, C12, C13, C14, C15, C16, C17, C18: 0.1uF; C_0603_1608Metric_Pad1.08x0.95mm_HandSolder
D1, D2, D3, D4, D8, D9, D10, D11, D12, D13, D14: WS2812B_Unified; WS2812B-2835_EMBED_DoubleSide
DL1, DL2, DL3, DL4: WS2812B_Unified; WS2812B-4020
DL5, DL6, DL7, DL8, DL9: WS2812B_Unified; WS2812B-4020_UP
DR1, DR2, DR3, DR4: WS2812B_Unified; WS2812B-4020
DR5, DR6, DR7, DR8, DR9: WS2812B_Unified; WS2812B-4020_UP
H1, H2, H3, H4, H5, H6: SS49E_SOT23; SOT-23-FAT
JL1: Hall; SH1.0_4P_Solder_Combo
JL2: BT; SH1.0_4P_Solder_Combo
JL3: AUX; SH1.0_4P_Solder_Combo
JL4: VOL; SH1.0_4P_Solder_Combo
JL5: RGB; SH1.0_4P_Solder_Combo
JR1: HALL_BT; SH1.0_4P_Solder_Combo
JR3: AUX; SH1.0_4P_Solder_Combo
JR4: VOL; SH1.0_4P_Solder_Combo
JR5: RGB; SH1.0_4P_Solder_Combo
R1, R2, R3, R4: 5K1; R_0603_1608Metric_Pad0.98x0.95mm_HandSolder
R5: 1K; R_0603_1608Metric_Pad0.98x0.95mm_HandSolder
R6: 50K; R_0603_1608Metric_Pad0.98x0.95mm_HandSolder
U1: PiPico; RPi_Pico_SMD_No_SWD
U2: ADG708BRUZ; TSSOP-16_4.4x5mm_P0.65mm
U3, U4: TMAG5273; TSOT-23-6_HandSoldering
U6: LM4040DBZ-2.1; SOT-23-FAT
U7: LP5907MFX-4.2; SOT-23-5
USB1: U262-161N-4BVC11; HRO-TYPE-C-31-M-12-Assembly
Z1: 3.3V; D_SOD-123F

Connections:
+3V3: R3.1, R4.1, U1.36 (3V3)
/D+: U1.TP3 (USB2), USB1.6 (DP1), USB1.8 (DP2)
/D-: U1.TP2 (USB1), USB1.5 (DN2), USB1.7 (DN1)
/K1: B3.1 (A), U1.14 (GPIO10)
/K2: B1.1 (A), U1.12 (GPIO9)
/K3: B2.1 (A), U1.11 (GPIO8)
/K4: JL2.1, U1.10 (GPIO7)
/K5: JL2.2, U1.9 (GPIO6)
/K6: JL2.3, U1.7 (GPIO5)
/K7: B4.1 (A), U1.6 (GPIO4)
/K8: B5.1, JR3.2, U1.5 (GPIO3)
/K9: JL3.2, U1.4 (GPIO2)
/KX: JL3.3, U1.21 (GPIO16)
/KXR: B4.3 (C), JR3.3
/LED_BT: D1.I (In), D8.I (In), U1.17 (GPIO13)
/LED_BT_R: D3.IB (InB), D4.O (Out), D12.IB (InB), D13.IB (InB), D14.IB (InB), JL5.2, JR5.2
/LED_L: DL1.I (In), U1.19 (GPIO14)
/LED_R: DR1.I (In), JL5.3, JR5.3, U1.20 (GPIO15)
/S1: H5.2 (OUT), U2.4 (S1)
/S2: H1.2 (OUT), U2.5 (S2)
/S3: H2.2 (OUT), U2.6 (S3)
/S4: JL1.1, U2.7 (S4)
/S4_K4_R: B2.3 (C), H3.2 (OUT), JR1.1
/S5: JL1.3, U2.12 (S5)
/S5_K6_R: B3.3 (C), H6.2 (OUT), JR1.3
/S6: JL1.2, U2.11 (S6)
/S6_K5_R: B1.3 (C), H4.2 (OUT), JR1.2
/SCL: JL4.2, JR4.2, R3.2, U1.2 (GPIO1), U3.1 (SCL), U4.1 (SCL)
/SDA: JL4.3, JR4.3, R4.2, U1.1 (GPIO0), U3.6 (SDA), U4.6 (SDA)
/V1: C3.1, U1.16 (GPIO12), U3.4 (VCC)
/V2: C4.1, JL4.1, JR4.1, U1.15 (GPIO11), U4.4 (VCC)
GND: B1.2 (B), B2.2 (B), B3.2 (B), B4.2 (B), B5.2, C1.2, C2.2, C3.2, C4.2, C5.2, C7.2, C8.2, C9.2, C10.2, C11.2, C12.2, C13.2, C14.2, C15.2, C16.2, C17.2, C18.2, D1.G (VSS), D2.G (VSS), D3.G (VSS), D4.G (VSS), D8.G (VSS), D9.G (VSS), D10.G (VSS), D11.G (VSS), D12.G (VSS), D13.G (VSS), D14.G (VSS), DL1.G (VSS), DL2.G (VSS), DL3.G (VSS), DL4.G (VSS), DL5.G (VSS), DL6.G (VSS), DL7.G (VSS), DL8.G (VSS), DL9.G (VSS), DR1.G (VSS), DR2.G (VSS), DR3.G (VSS), DR4.G (VSS), DR5.G (VSS), DR6.G (VSS), DR7.G (VSS), DR8.G (VSS), DR9.G (VSS), H1.3 (G), H2.3 (G), H5.3 (G), JL1.4, JL2.4, JL3.4, JL4.4, JL5.4, JR3.4, JR4.4, JR5.4, R1.2, R2.2, R6.1, U1.3 (GND), U1.8 (GND), U1.13 (GND), U1.18 (GND), U1.23 (GND), U1.28 (GND), U1.33 (AGND), U1.38 (GND), U2.3 (VSS), U2.14 (GND), U3.2 (GND), U3.3 (TEST), U4.2 (GND), U4.3 (TEST), U6.2 (A), U7.2 (GND), USB1.1 (GND), USB1.12 (GND), USB1.13 (SHIELD), Z1.2 (A)
Gref: C6.2, H3.3 (G), H4.3 (G), H6.3 (G), JR1.4
unnamed: D1.IB (InB), D2.OB (OutB), D8.IB (InB)
unnamed: D1.O (Out), D2.I (In), D9.I (In), D10.I (In), D11.I (In)
unnamed: D1.OB (OutB), D4.IB (InB)
unnamed: D3.O (Out), D4.I (In)
unnamed: D2.IB (InB), D3.OB (OutB), D9.IB (InB), D10.IB (InB), D11.IB (InB)
unnamed: D2.O (Out), D3.I (In), D12.I (In), D13.I (In), D14.I (In)
unnamed: DL1.O (Out), DL2.I (In)
unnamed: DL2.O (Out), DL3.I (In)
unnamed: DL3.O (Out), DL4.I (In)
unnamed: DL4.O (Out), DL5.I (In)
unnamed: DL5.O (Out), DL6.I (In)
unnamed: DL6.O (Out), DL7.I (In)
unnamed: DL7.O (Out), DL8.I (In)
unnamed: DL8.O (Out), DL9.I (In)
unnamed: DR1.O (Out), DR2.I (In)
unnamed: DR2.O (Out), DR3.I (In)
unnamed: DR3.O (Out), DR4.I (In)
unnamed: DR4.O (Out), DR5.I (In)
unnamed: DR5.O (Out), DR6.I (In)
unnamed: DR6.O (Out), DR7.I (In)
unnamed: DR7.O (Out), DR8.I (In)
unnamed: DR8.O (Out), DR9.I (In)
unnamed: U1.35 (ADC_VREF), U6.1 (K)
unnamed: U1.24 (GPIO18), U2.2 (EN)
unnamed: U1.25 (GPIO19), U2.15 (A2)
unnamed: U1.26 (GPIO20), U2.16 (A1)
unnamed: U1.27 (GPIO21), U2.1 (A0)
unnamed: R5.2, R6.2, U1.31 (GPIO26_ADC0), U1.32 (GPIO27_ADC1), Z1.1 (K)
unnamed: R5.1, U2.8 (D)
unnamed: R1.1, USB1.4 (CC1)
unnamed: R2.1, USB1.10 (CC2)
VBUS: C1.1, U1.40 (VBUS), U7.1 (IN), U7.3 (EN), USB1.2 (VBUS), USB1.11 (VBUS)
VLED: C7.1, C8.1, C9.1, C10.1, C11.1, C12.1, C13.1, C14.1, C15.1, C16.1, C17.1, C18.1, D1.V (VDD), D2.V (VDD), D3.V (VDD), D4.V (VDD), D8.V (VDD), D9.V (VDD), D10.V (VDD), D11.V (VDD), D12.V (VDD), D13.V (VDD), D14.V (VDD), DL1.V (VDD), DL2.V (VDD), DL3.V (VDD), DL4.V (VDD), DL5.V (VDD), DL6.V (VDD), DL7.V (VDD), DL8.V (VDD), DL9.V (VDD), DR1.V (VDD), DR2.V (VDD), DR3.V (VDD), DR4.V (VDD), DR5.V (VDD), DR6.V (VDD), DR7.V (VDD), DR8.V (VDD), DR9.V (VDD), JL5.1, JR5.1, U1.39 (VSYS)
Vref: C2.1, C5.1, C6.1, H1.1 (V), H2.1 (V), H3.1 (V), H4.1 (V), H5.1 (V), H6.1 (V), JL3.1, JR3.1, U2.13 (VDD), U7.5 (OUT)

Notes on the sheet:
Hall and BT Shared

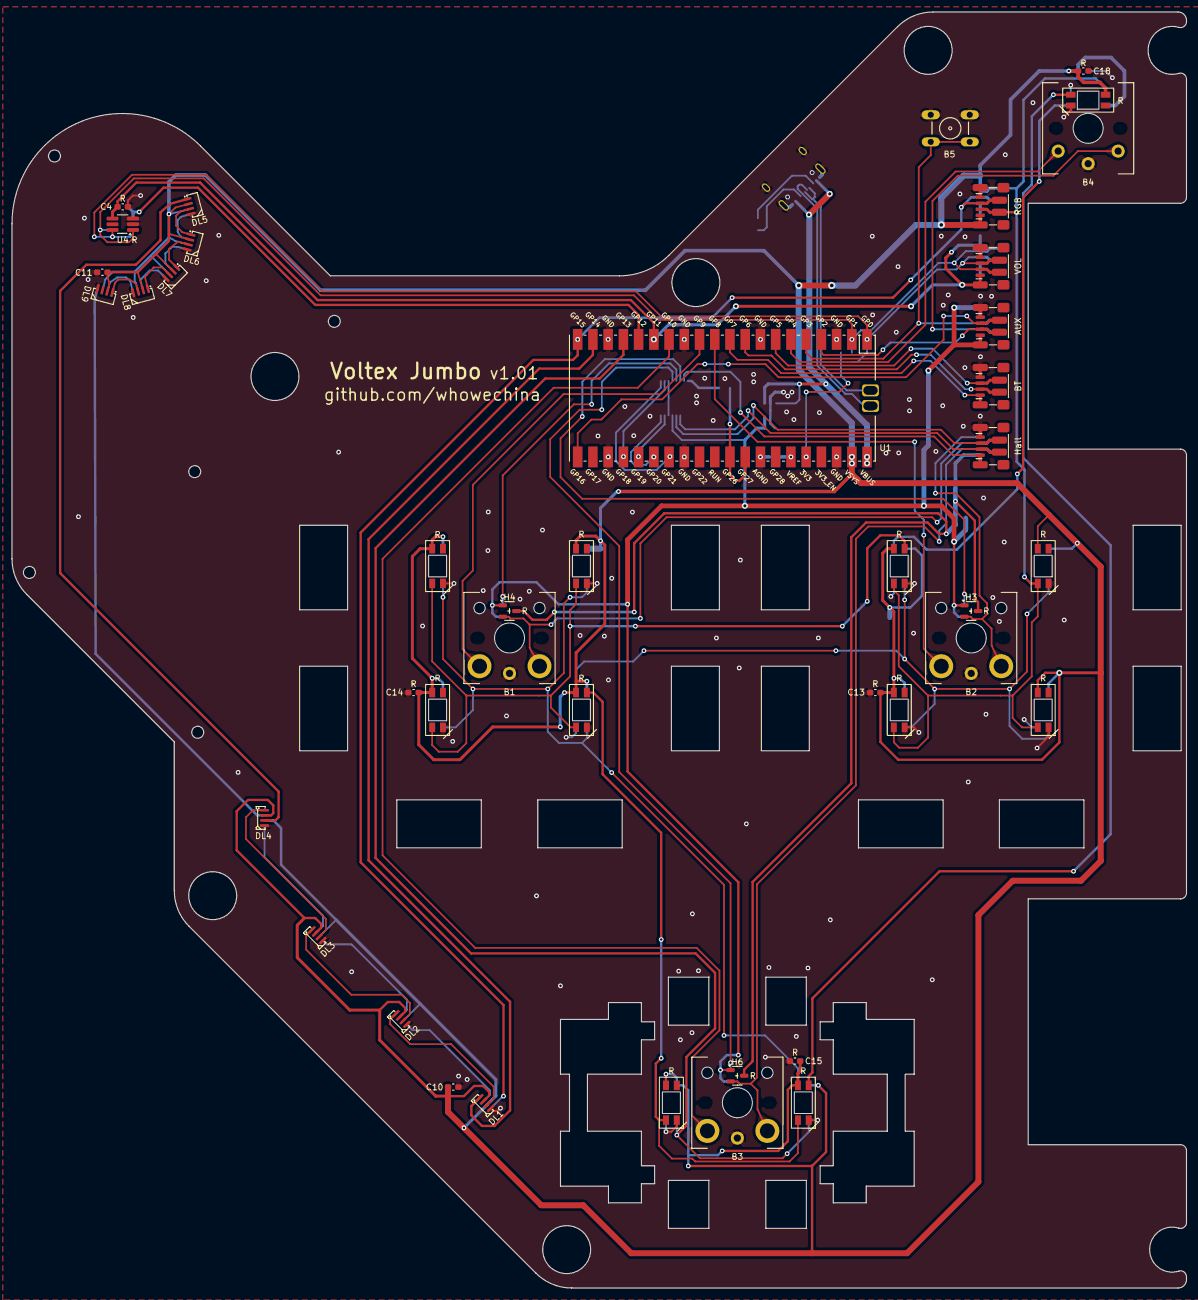
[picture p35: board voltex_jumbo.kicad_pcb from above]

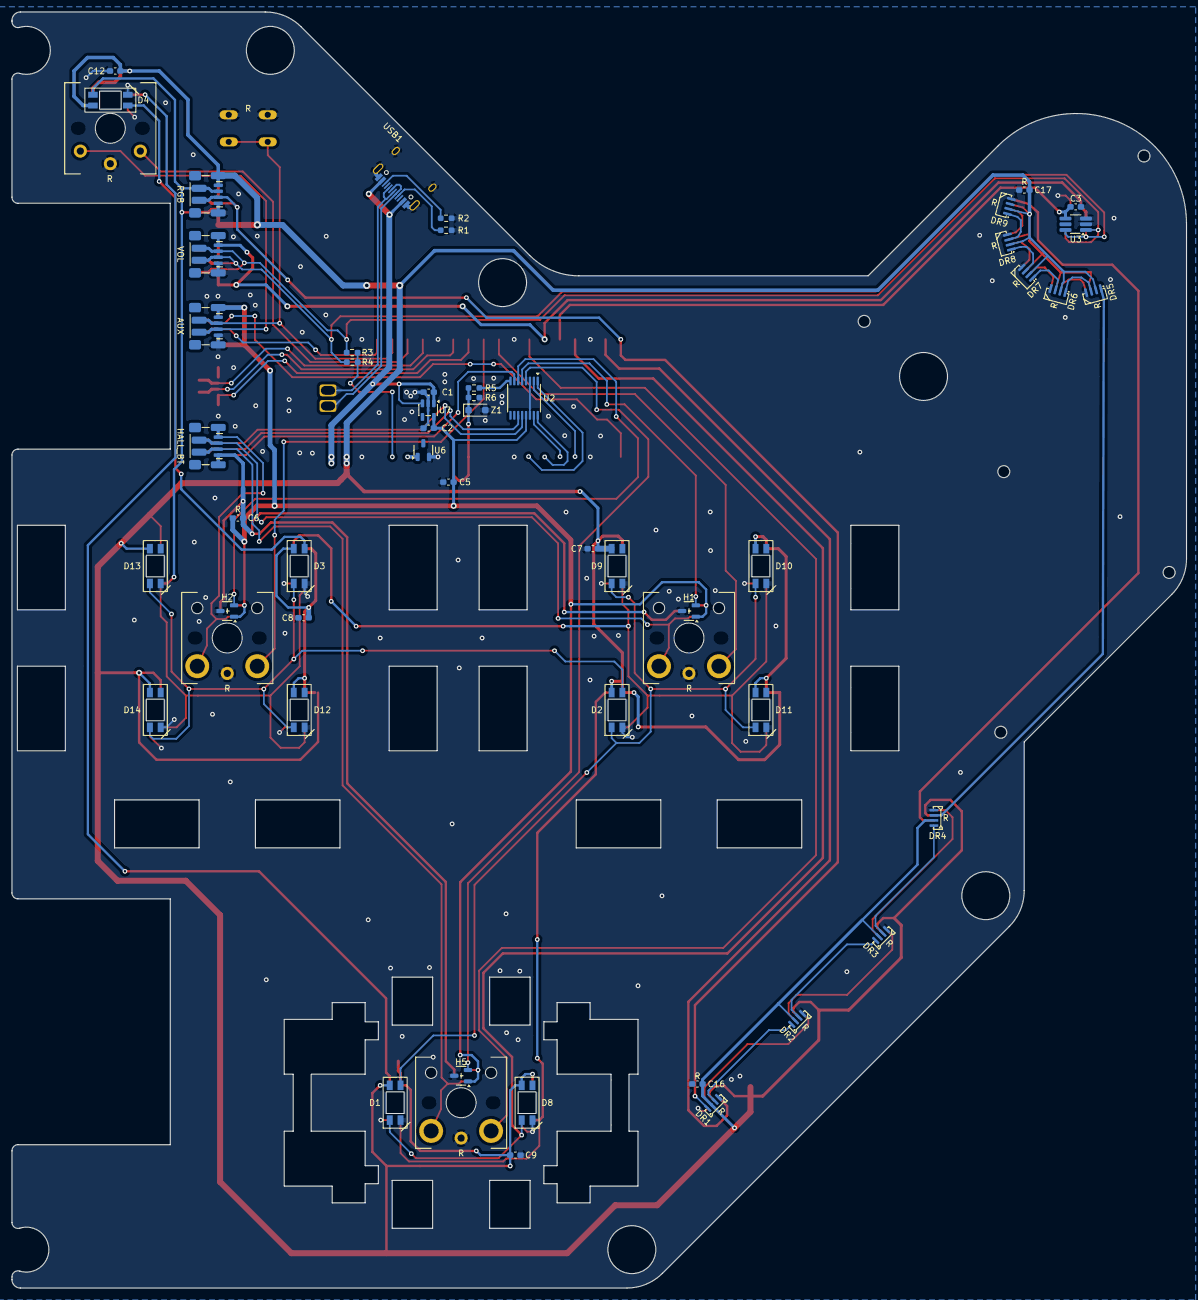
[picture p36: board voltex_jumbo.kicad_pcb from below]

Board: 2 copper layers, 195.9 x 212.8 mm, 81 parts (50 on the bottom side), 67 nets.

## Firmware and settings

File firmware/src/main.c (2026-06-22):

/*
 * Controller Main
 * WHowe <github.com/whowechina>
 */

#include <stdlib.h>
#include <stdint.h>
#include <stdbool.h>

#include "pico/stdio.h"
#include "pico/stdlib.h"
#include "bsp/board.h"
#include "pico/multicore.h"
#include "pico/bootrom.h"

#include "hardware/gpio.h"
#include "hardware/sync.h"
#include "hardware/structs/ioqspi.h"
#include "hardware/structs/sio.h"

#include "tusb.h"
#include "usb_descriptors.h"

#include "board_defs.h"

#include "save.h"
#include "config.h"
#include "cli.h"
#include "commands.h"

#include "light.h"
#include "button.h"
#include "spin.h"
#include "hebtn.h"

#define AUX_1_MASK 0x0100
#define AUX_2_MASK 0x0080
#define ALL_BUTTON_MASK 0x7f
#define VIRTUAL_BUTTON_SHIFT 7

static void run_lights()
{
    uint16_t button = button_read();

    bool left_shift = (button & AUX_1_MASK);
    bool right_shift = (button & AUX_2_MASK);

    bool slow_flash = (time_us_32() >> 17) & 1;

    for (int i = 0; i < 7; i++) {
        if (hebtn_actuated(i) || (button & (1 << i))) {
            uint32_t color = (i == 6) ? rgb32(0, 0, 255, false) : rgb32(255, 0, 0, false);
            light_set_button(i, color, false);
        } else if (left_shift && right_shift) {
            uint32_t color = slow_flash ? rgb32(0, 64, 64, false) : 0;
            light_set_button(i, color, false);
        } else if (left_shift || right_shift) {
            uint32_t color = slow_flash ? rgb32(64, 64, 0, false) : 0;
            light_set_button(i, color, false);
        } else {
            uint32_t phase = time_us_32() >> 14;
            uint32_t rainbow = rgb32_from_hsv(phase + i * 30, 255, 64);
            light_set_button(i, rainbow, false);
        }
    }

    uint16_t left = spin_read(0) * 255 / 360 / 16;
    uint16_t right = spin_read(1) * 255 / 360 / 16;
    for (int i = 0; i < 5; i++) {
        light_set_knob(0, i, rgb32_from_hsv(255 + i * 30 - left, 255, 128), false);
        light_set_knob(1, i, rgb32_from_hsv(255 + i * 30 + right, 255, 128), false);
    }

    uint32_t phase = time_us_32() >> 14;
    for (int i = 0; i < 4; i++) {
        uint32_t color = rgb32_from_hsv(phase - i * 20, 255, 255);
        light_set_wing(0, i, color, false);
        light_set_wing(1, i, color, false);
    }

}

static mutex_t core1_io_lock;
static void core1_loop()
{
    while (1) {
        if (mutex_try_enter(&core1_io_lock, NULL)) {
            run_lights();
            light_update();
            mutex_exit(&core1_io_lock);
        }
        cli_fps_count(1);
        sleep_us(700);
    }
}

struct __attribute__((packed)) {
    uint32_t buttons;
    uint8_t joy[2];
} hid_report, old_hid_report;

struct __attribute__((packed)) {
    uint8_t joy[2];
    uint16_t buttons;
} hid_spoof_report;

static bool do_hid_report()
{
    if (voltex_runtime.hid.spoofed) {
        hid_spoof_report.buttons = hid_report.buttons & 0x3f;
        hid_spoof_report.buttons |= (hid_report.buttons & 0x40) ? 0x100 : 0;
        hid_spoof_report.joy[0] = hid_report.joy[0];
        hid_spoof_report.joy[1] = hid_report.joy[1];
        return tud_hid_report(0, &hid_spoof_report, sizeof(hid_spoof_report));
    } else {
        return tud_hid_n_report(0, REPORT_ID_JOYSTICK, &hid_report, sizeof(hid_report));
    }
}

static void hid_update()
{
    uint32_t buttons = button_read();
    for (int i = 0; i < 6; i++) {
        if (hebtn_actuated(i)) {
            buttons |= (1 << i);
        }
    }

    hid_report.buttons = buttons & ALL_BUTTON_MASK;

    bool left_aux = buttons & AUX_1_MASK;
    bool right_aux = buttons & AUX_2_MASK;
    if (left_aux || right_aux) {
        hid_report.buttons <<= VIRTUAL_BUTTON_SHIFT;
    }
    if (left_aux && right_aux) {
        hid_report.buttons <<= VIRTUAL_BUTTON_SHIFT;
    }

    for (int i = 0; i < 2; i++) {
        hid_report.joy[i] = spin_units(i);
    }

    if (tud_hid_ready()) {
        if ((memcmp(&hid_report, &old_hid_report, sizeof(hid_report)) != 0) &&
             do_hid_report()) {
            old_hid_report = hid_report;
        }
    }
}

static void core0_loop()
{
    uint64_t next_frame = 0;
    while(1) {
        tud_task();

        cli_run();

        save_loop();
        cli_fps_count(0);

        button_update();
        spin_update();
        hebtn_update();

        hid_update();

        sleep_until(next_frame);
        next_frame += 1000;
    }
}

/* if certain key pressed when booting, enter update mode */
static void update_check()
{
    const uint8_t pins[] = BUTTON_DEF;
    // AUX 1 and AUX 2
    for (int i = 7; i < 9; i++) {
        uint8_t gpio = pins[i];
        gpio_init(gpio);
        gpio_set_function(gpio, GPIO_FUNC_SIO);
        gpio_set_dir(gpio, GPIO_IN);
        gpio_pull_up(gpio);
        sleep_ms(1);
        if (gpio_get(gpio)) {
            return;
        }
    }

    sleep_ms(100);
    reset_usb_boot(0, 2);
}

static void mode_check()
{
    button_update();
    uint16_t button = button_read();
    if (button & (1 << 7)) {
        voltex_cfg->hid.spoof = true;
        config_changed();
    } else if (button & (1 << 8)) {
        voltex_cfg->hid.spoof = false;
        config_changed();
    }

    voltex_runtime.hid.spoofed = voltex_cfg->hid.spoof;
    if (voltex_runtime.hid.spoofed) {
        enable_konami_spoof();
    }
}

static void pico_led_off()
{
    gpio_init(25);
    gpio_set_dir(25, GPIO_IN);
}

void init()
{
    sleep_ms(50);
    board_init();

    update_check();

    config_init();
    mutex_init(&core1_io_lock);
    save_init(0xca44cabe, &core1_io_lock);

    light_init();
    button_init();
    spin_init();
    hebtn_init();

    mode_check();
    pico_led_off();

    tusb_init();
    stdio_init_all();

    cli_init("voltex_pico>", "\n   << Voltex Pico Controller >>\n"
                            " https://github.com/whowechina\n\n");
    
    commands_init();
}

int main(void)
{
    init();
    multicore_launch_core1(core1_loop);
    core0_loop();
    return 0;
}

// Invoked when received GET_REPORT control request
// Application must fill buffer report's content and return its length.
// Return zero will cause the stack to STALL request
uint16_t tud_hid_get_report_cb(uint8_t itf, uint8_t report_id,
                               hid_report_type_t report_type, uint8_t *buffer,
                               uint16_t reqlen)
{
    printf("Get from USB %d-%d\n", report_id, report_type);
    return 0;
}

// Invoked when received SET_REPORT control request or
// received data on OUT endpoint ( Report ID = 0, Type = 0 )
void tud_hid_set_report_cb(uint8_t itf, uint8_t report_id,
                           hid_report_type_t report_type, uint8_t const *buffer,
                           uint16_t bufsize)
{
    for (int i = 0; i < 7; i++) {
        light_set_button(i, rgb32_from_hsv(0, 0, buffer[i]), true);
    }
    uint32_t knob1 = rgb32(buffer[7], buffer[8], buffer[9], false);
    uint32_t knob2 = rgb32(buffer[10], buffer[11], buffer[12], false);
    for (int i = 0; i < 5; i++) {
        light_set_knob(0, i, knob1, true);
        light_set_knob(1, i, knob2, true);
    }
    uint32_t wing1 = rgb32(buffer[13], buffer[14], buffer[15], false);
    uint32_t wing2 = rgb32(buffer[16], buffer[17], buffer[18], false);
    for (int i = 0; i < 4; i++) {
        light_set_wing(0, i, wing1, true);
        light_set_wing(1, i, wing2, true);
    }
}

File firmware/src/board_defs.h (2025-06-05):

/*
 * Voltex Controller Board Definitions
 * WHowe <github.com/whowechina>
 */

#if defined BOARD_VOLTEX_PICO

#define RGB_PIN_MAIN 13
#define RGB_PIN_LEFT 14
#define RGB_PIN_RIGHT 15

#define RGB_ORDER GRB // or RGB

#define BUS_I2C i2c0
#define BUS_I2C_SDA 0
#define BUS_I2C_SCL 1
#define BUS_I2C_FREQ 400*1000

#define SPIN_DEF { 12, 11 }
 
 /* BT * 4, FX * 2, START, AUX * 2 */
#define BUTTON_DEF { 9, 8, 7, 6, 10, 5, 4, 3, 2 }
#define BUTTON_LIGHT_MAP { 1, 2, 4, 5, 0, 6, 3, 7, 8 }

#define ADC_MUX_EN 18
#define ADC_MUX_A0 21
#define ADC_MUX_A1 20
#define ADC_MUX_A2 19

#define ADC_CHANNEL 0

#define ADC_KEY_NUM 6
#define ADC_KEY_CHN { 1, 2, 3, 5, 0, 4 }

#else

#endif

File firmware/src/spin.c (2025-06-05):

/*
 * The Spinning of Buttons
 * WHowe <github.com/whowechina>
 * 
 */

#include "spin.h"

#include <stdint.h>
#include <stdbool.h>

#include "hardware/gpio.h"
#include "hardware/timer.h"
#include "hardware/pwm.h"

#include "board_defs.h"
#include "config.h"

#include "tmag5273.h"

static const uint8_t spin_enablers[] = SPIN_DEF;
const uint16_t FULL_SCALE = 360 * 16;

#define SPIN_NUM (count_of(spin_enablers))

void spin_init()
{
    gpio_init(BUS_I2C_SDA);
    gpio_set_function(BUS_I2C_SDA, GPIO_FUNC_I2C);
    gpio_pull_up(BUS_I2C_SDA);
    gpio_init(BUS_I2C_SCL);
    gpio_set_function(BUS_I2C_SCL, GPIO_FUNC_I2C);
    gpio_pull_up(BUS_I2C_SCL);
    i2c_init(BUS_I2C, BUS_I2C_FREQ);

    for (int i = 0; i < SPIN_NUM; i++) {
        uint8_t ce = spin_enablers[i];
        gpio_init(ce);
        gpio_set_dir(ce, GPIO_OUT);
        gpio_put(ce, 1);
        sleep_us(1000);
        tmag5273_init(i, BUS_I2C);
        tmag5273_init_sensor();
    }
}

uint8_t spin_num()
{
    return SPIN_NUM;
}

bool spin_present(uint8_t index)
{
    if (index >= SPIN_NUM) {
        return false;
    }
    return tmag5273_is_present(index);
}

static uint16_t spin_reading[SPIN_NUM];

void spin_update()
{
    static bool flip = false;
    flip = !flip;

    for (int i = 0; i < SPIN_NUM; i++) {
        if (flip ^ (i % 2)) {
            continue;
        }
        tmag5273_use(i);
        spin_reading[i] = tmag5273_read_angle();
        if (voltex_cfg->knob.reversed[i]) {
            spin_reading[i] = FULL_SCALE - spin_reading[i];
        }
    }
}

uint16_t spin_read(uint8_t index)
{
    if (index >= SPIN_NUM) {
        return 0;
    }
    return spin_reading[index];
}

uint16_t spin_units(uint8_t index)
{
    static uint16_t last[SPIN_NUM] = {0};
    static int counter[SPIN_NUM] = {0};

    if (index >= SPIN_NUM) {
        return 0;
    }

    int delta = spin_reading[index] - last[index];
    if (delta > FULL_SCALE / 2) {
        delta -= FULL_SCALE;
    } else if (delta < -FULL_SCALE / 2) {
        delta += FULL_SCALE;
    }

    int resolution = FULL_SCALE / voltex_cfg->knob.units_per_turn;
    if ((delta <= -resolution) || (delta >= resolution)) {
        last[index] = spin_reading[index];
        counter[index] += delta;
    }

    return counter[index] * voltex_cfg->knob.units_per_turn / FULL_SCALE;
}

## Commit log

2025-05-26 PCB work started
    [530470310.stp, 8002A.step, Button Cap.step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]
2025-05-27 PCB progress 70%
    [voltex_pico.kicad_pcb, voltex_pico.kicad_sch]
2025-05-30 PCB done for review
    [Voltex Pico - PCB Profile.dxf, voltex_pico.kicad_pcb, voltex_pico.kicad_sch]
2025-06-02 PCB v1.0
    [Logo_font_axion.dxf, Voltex Pico - PCB Profile.dxf, voltex_pico.kicad_pcb]
2025-06-06 HE button works
2025-06-14 PCB v1.11
    [Housing - PCB.dxf, Voltex Pico - PCB Profile.dxf, skhhana010.stp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]
2025-06-24 Ready to publish
    [Voltex Pico - BT Choc V2.stl, Voltex Pico - Bearing Fixer.stl, Voltex Pico - FX-L Choc V1.stl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]
2025-06-25 README in CN
    [Voltex Pico - BT Choc V1.stl]
2025-06-25 Notes on magnetic switch
2025-07-03 Fix screw columns in base part
2025-07-05 Ignore hall button when no hall sensor
2025-07-12 Fix bearing model
2025-09-18 HE button defaults
2025-09-30 Fix housing screw description
2025-10-01 Fix START key mapping in spoof mode
    [main.c]
2025-12-07 Heatset inserts support and fix for taller switches
    [Voltex Pico - BT Choc V2_TallFix.stl, Voltex Pico - FX-L Choc V2_TallFix.stl, Voltex Pico - FX-R Choc V2_TallFix.stl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]
2025-12-08 Optimize screw holes
    [Voltex Pico - Base.stl, Voltex Pico - Left Wing Base.stl, Voltex Pico - Magnet Seat.stl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]
2025-12-12 PCB Pico v1.2 (remove unused parts)
    [voltex_pico.kicad_pcb, voltex_pico.kicad_sch, voltex_pico_3d.step]
2026-01-01 Recover Bambu Studio ruined file
    [Voltex Pico - Panel Combo_Insert.3mf]
2026-01-15 Use commercial keycap for START
    [Voltex Pico - Panel Combo.3mf, Voltex Pico - Panel Combo_Insert.3mf, Voltex Pico - START Choc V1.stl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]
2026-03-18 PCB v1.3 (use FPC)
    [FPC6P_1.0mm_Bottom_Contact_Flip.stp, voltex_pico.kicad_pcb, voltex_pico.kicad_sch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]
2026-03-18 PCB v1.31 (FPC alignment)
    [voltex_pico.kicad_pcb, voltex_pico_3d.step]
2026-03-18 Enlarge base screw hole sinks
    [Voltex Pico - Base.stl, Voltex Pico - Left Wing Base.stl, Voltex Pico - Right Wing Base.stl]
2026-03-18 Doc update after PCBv1.3
2026-03-18 PCB image update
2026-03-23 Turn off pico led
2026-06-22 Optimize screw description
2026-08-16 Jumbo PCB work started
    [530470310.stp, 698b116-264-211.STEP, 8002A.step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]
2026-08-18 Jumbo PCB continued
    [voltex_jumbo.kicad_pcb, voltex_jumbo.kicad_sch, voltex_jumbo_font_axion.dxf]
2026-08-19 Jumbo PCB v1.0
    [voltex_jumbo.kicad_pcb, voltex_jumbo.kicad_sch, voltex_jumbo_3d.step]
2026-08-23 Jumbo PCB v1.01 (silkscreen fix)
    [Voltex Jumbo - PCB EdgeCut.dxf, voltex_jumbo.kicad_pcb]
2026-08-23 Tiny PCB edgecut finetune
    [Voltex Jumbo - PCB EdgeCut.dxf, voltex_jumbo.kicad_pcb]
2026-09-25 Better button stem
2026-09-25 Voltex Jumbo 3D files
2026-11-12 PCB v1.02 (fix right side mark for connectors)
2026-11-12 Update readme for Voltex Jumbo
